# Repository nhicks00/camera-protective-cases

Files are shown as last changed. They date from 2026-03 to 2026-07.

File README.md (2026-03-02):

# Camera Protective Cases (Mevo Start + BirdDog MAKI Live)

Parametric, 3D-printable protective case design workspace for two cameras:
- Mevo Start
- BirdDog MAKI Live

All geometry generation is built with `build123d` (OpenCascade B-REP) and exported as STEP for clean, smooth CAD surfaces.

## Goals
- Tight-fitting protective sleeves for outdoor sports production
- Impact resistance (volleyball strike scenarios)
- Heat/sun durable outer shell (ASA-focused)
- Optional TPU inner shock/fit components
- Precise cutout alignment with device features and ports

## Repository Structure
- `scripts/`: parametric generators for sleeves, liners, and caps
- `models/mevo_case/`: generated Mevo STEP outputs
- `models/mevo_case/reports/`: generated Mevo JSON reports
- `models/maki_case/`: generated MAKI STEP outputs
- `models/maki_case/reports/`: generated MAKI JSON reports
- `refs/`: source reference CAD/STL/PDF assets used for extraction and alignment
- `README_MEVO_CASE.md`: Mevo-specific generator details
- `README_MAKI_CASE.md`: MAKI-specific generator details
- `CHANGELOG.md`: project changelog and current status

## Core Scripts
- `scripts/generate_mevo_case.py`
- `scripts/generate_mevo_start_caps.py`
- `scripts/generate_mevo_start_tpu_liner.py`
- `scripts/generate_mevo_dual_material_case.py`
- `scripts/generate_maki_live_case.py`
- `scripts/generate_maki_live_tpu_liner.py`
- `scripts/generate_maki_live_dual_material_body.py`
- `scripts/generate_maki_live_caps.py`

## Current Outputs
Key generated outputs are in `models/`, including:
- Mevo dual-material body (`TPU_Sleeve` + `ASA_Shell`) + dual-material back cap (`ASA_Back_Cap` + `TPU_Back_Gasket`)
- MAKI ASA sleeve + front/rear caps + TPU sleeve + combined dual-material body (`TPU_Sleeve` + `ASA_Shell`)
- JSON reports for extracted/applied features and dimensions

## Regeneration
```bash
source .venv311/bin/activate

python scripts/generate_mevo_case.py
python scripts/generate_mevo_start_caps.py --profile asa
python scripts/generate_mevo_start_tpu_liner.py
python scripts/generate_mevo_dual_material_case.py

python scripts/generate_maki_live_case.py
python scripts/generate_maki_live_tpu_liner.py
python scripts/generate_maki_live_dual_material_body.py
python scripts/generate_maki_live_caps.py --profile asa
python scripts/generate_maki_live_caps.py --profile tpu
```

Legacy optional command (not part of current Mevo TPU path):
```bash
python scripts/generate_mevo_start_caps.py --profile tpu
```

## Notes
- STEP-only workflow is used for production models.
- Temporary meshes/renders are excluded from version control.
- Output rollover policy:
  - each generator archives existing outputs into `models/mevo_case/archive/` or `models/maki_case/archive/` before writing new files,
  - top-level case folders keep only latest STEP outputs while JSON reports live under each case's `reports/` subfolder.
- See `CHANGELOG.md` for latest engineering status and open alignment tasks.

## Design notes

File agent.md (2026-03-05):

# Agent Context: Camera Protective Cases (Mevo Start + BirdDog MAKI Live)

This file is the persistent handoff context for future sessions.

## Scope
This repo builds parametric, 3D-printable protective case components for:
- Mevo Start
- BirdDog MAKI Live

Primary goals:
- Tight fit
- Outdoor durability
- Impact resistance
- Clean, smooth CAD geometry (not faceted mesh-style approximations)

## Core Modeling Rules
- Use `build123d` (OpenCascade B-REP).
- Export STEP files for deliverables.
- Keep curves smooth; avoid tiny rectangular facet chains for curved surfaces.
- Keep generated outputs organized by camera and archive prior versions.

## Confirmed Dimension Baseline
Use these as the current default stack unless user explicitly overrides.

Mevo Start:
- Device envelope reference: `87.0 x 75.5 x 34.0 mm` (L x H x W)
- TPU inner cavity (active fit): `34.3 x 75.8 x 87.3 mm` (W x H x depth)
- TPU wall: `1.8 mm`
- TPU inner vertical corner fillet: `4.0 mm`
- TPU-to-ASA interface gap: `0.0 mm` (coincident interface)
- ASA shell wall: `2.2 mm`
- ASA outer vertical corner fillet: `6.0 mm`
- Front bucket/sun hood depth: `3.0 mm`
- Front lens cutout: `32.0 mm`
- Front tally LED hole: `3.0 mm`, centered `12.0 mm` above lens center
- Bottom tripod hole: `20.5 mm` diameter, center `43.2 mm` from front face
- ASA back-cap plug lip: `5.0 mm` depth, `0.1 mm` total undersize
- Back utility slot: `15.0 mm` wide, top margin `15.0 mm`, bottom margin `10.0 mm`

BirdDog MAKI Live:
- Device envelope: `120.32 x 56.99 x 56.99 mm` (L x W x H)
- ASA shell wall: `3.0 mm`
- ASA radial clearance to device: `2.3 mm`
- TPU sleeve wall: `2.0 mm`
- TPU radial device clearance: `0.15 mm`
- TPU-to-ASA radial air gap: `0.15 mm` per side (current dual-body default stack)
- ASA cap plug depth: `1.8 mm`

Slicer baseline (ASA):
- 4 wall loops/perimeters minimum.

## Output Organization Policy
- Current outputs:
  - `models/mevo_case/`
  - `models/mevo_case/reports/`
  - `models/maki_case/`
  - `models/maki_case/reports/`
- Each generator archives old versions into:
  - `models/mevo_case/archive/`
  - `models/maki_case/archive/`
- Top-level in each case folder should show only latest STEP outputs for that case.
- JSON reports should live in each case's `reports/` subfolder.

## Current Project State

### MAKI Live (BirdDog)
Active hard-shell and TPU workflows:
- ASA sleeve:
  - `models/maki_case/maki_live_case_sleeve.step`
  - Generator: `scripts/generate_maki_live_case.py`
  - Front is integrated into sleeve by default (`front_integrated=True`).
  - Front cutouts are extracted from STEP and cut through the integrated front wall.
  - Back remains open for separate rear cap installation.
  - Tripod detection is STEP-interrogation-first:
    - cylindrical face detection (thread-radius target near 1/4"-20 geometry),
    - downward axis normal filter,
    - centerline/depth region filters,
    - circular-edge fallback only if cylindrical detection fails.
  - Vent behavior updated to enforced tripod-side 3-panel layout:
    - 8 vent slots on center panel
    - 8 on each adjacent panel
    - 24 total on that side
    - plus side vents: 3 on left side + 3 on right side
    - total applied vents on sleeve: 30
  - The 24-vent bank is constrained to bottom-connected panels (not direct side walls).
  - Side 3+3 vent group is placed on the opposite end from the tripod-side vent bank.
  - Side 3+3 vent dimensions are matched to the main tripanel vent style size.
  - Main `24` vent bank and side `3+3` vents use rounded-slot cuts on both ASA and TPU (not box/square cuts).
  - Vent-bank/tripod side relationship is explicit: 24-bank and tripod opening remain on the same expected side (`tripod_expected_side`), with hood on the opposite side.
  - Front camera aperture in integrated front wall is trimmed by `2.0 mm` vs prior extraction.
  - Through-cut depth increased so vents fully penetrate.
  - Vent row clustering now locks to the STEP-derived rear vent bank (8 rows) and ignores front outlier slots.
  - Tripod armor boss has been removed (params zeroed out).
  - Tripod hole cut orientation is corrected and validated as a true through-cut.
  - Dual-body tripod overlap is now numerically aligned (`dx=0.0`, `dz=0.0` in current reports).
  - Side `3 + 3` vents are rounded-slot cuts (not hard rectangular box cuts).
  - Integrated top-front lens hood/shade uses an extended curved duck-bill profile with curved root transition (`lens_hood_*` params in case script).
  - Vent pass-through validated (`30/30` total) and vent coordinates emitted in report under `step_side_features.vents_applied_entries`.
- ASA caps:
  - Active outputs:
    - `models/maki_case/maki_live_rear_cap_dual_material.step`
  - Generator: `scripts/generate_maki_live_rear_cap_dual_material.py`
  - Dual rear cap contains: `ASA_Back_Cap` + `TPU_Back_Gasket`.
  - TPU rear-cap body now includes:
    - full-face pad at plug-tip contact plane,
    - perimeter edge-wrap collar for back-edge/corner shock isolation,
    so the camera back contacts TPU instead of bare ASA.
  - Legacy rear-cap-only generator remains available (`scripts/generate_maki_live_caps.py --profile asa`).
  - Rear cutouts are extracted from all STEP solids with tiny-hole filtering to preserve port access cutouts over corner fastener holes.
  - Rear cap port cutouts include default oversize clearance (`cutout_extra_mm=1.5`) for cable boot/plastic strain-relief fit.
- TPU one-piece sleeve (preferred TPU output):
  - `models/maki_case/maki_live_tpu_sleeve.step`
  - Generator: `scripts/generate_maki_live_tpu_liner.py`
  - Single connected TPU sleeve with front edge wrap disabled (ASA front wall provides retention) and rear edge wrap disabled by default.
  - Rear remains open for insertion; rear-side TPU contact is handled by rear cap TPU gasket.
  - Side `3 + 3` vents are rounded-slot cuts to match ASA style.
  - Does not use full TPU face caps.
  - Vent pass-through validated (`30/30` through by ray-check), with tripod through-cut also validated.
  - Vent rows are aligned to the ASA sleeve vent coordinates in device frame.
  - Applied empirical vent alignment deltas from tripod-registered overlay:
    - tripanel bank Z shift: `-4.226 mm`
    - side-trio bank Z shift: `-13.397 mm`
  - 24-grid lateral spacing calibration:
    - center column remains fixed
    - left/right columns are inset toward center by `2.6 mm` each
    - resulting tripanel X centers: `-13.4, 0.0, +13.4 mm`
  - Legacy separate TPU liner/caps and unibody files are archived automatically.
- Dual-material body assembly (combined slicer object):
  - `models/maki_case/maki_live_body_dual_material.step`
  - Generator: `scripts/generate_maki_live_dual_material_body.py`
  - Contains two bodies: `TPU_Sleeve` + `ASA_Shell`.
  - TPU is auto-aligned into ASA cavity with report-verified fit stack (default `0.15 mm` radial gap each side, ~`2.1 mm` axial front/back gap).
  - Fit validation pipeline:
    - Script: `scripts/validate_maki_live_fit.py`
    - Output assembly: `models/maki_case/maki_live_fit_validation_assembly.step`
    - Output report: `models/maki_case/reports/maki_live_fit_validation_report.json`
    - Validates real device STEP placement inside body + rear cap and reports pairwise hard-collision volumes.
    - Also validates all major opening geometry against STEP-derived expectations:
      - 24 tripanel vents + 6 side vents for both ASA and TPU bodies,
      - tripod opening alignment for both ASA and TPU,
      - rear-cap cutout center/size matching against STEP-derived rear port cutouts.
    - Current baseline result: no hard collisions and all feature checks passing.

### Mevo Start
Current preferred workflow:
- Dual-material bucket-body workflow (primary):
  - `models/mevo_case/mevo_start_body_dual_material.step`
  - `models/mevo_case/mevo_start_back_cap_dual_material.step`
  - Generator: `scripts/generate_mevo_dual_material_case.py`
  - Body STEP contains named solids: `TPU_Sleeve`, `ASA_Shell`.
  - Back-cap dual STEP contains named solids: `ASA_Back_Cap`, `TPU_Back_Insert`.
- Geometry intent:
  - ovular/capsule-profile sleeve geometry (not rounded-rectangle profile),
  - front-integrated body by default (front wall fused to sleeve),
  - TPU body uses front edge wrap only (rear wrap disabled) to keep insertion path open,
  - front lens/LED cutouts enabled by default in closed-front mode,
  - lens opening defaults updated to `29.5 mm` at `Y=20.0` for improved framing,
  - integrated curved duck-bill front visor is enabled by default (`depth=16 mm`, `drop=9 mm`, `span_ratio=0.90`),
  - thermal venting defaults: top holes enabled plus side slot vents enabled; top-hole plane orientation is corrected to the hood/top side,
  - separate back-cap assembly with TPU gasket (ASA-only cap exported for compatibility),
  - manual two-cutout rear-cap layout is default-enabled (`include_manual_back_cutouts=true`):
    - lower slot from Mevo edge offsets (10 mm side margins, 7 mm bottom offset),
    - upper domed cutout using top offsets (3.0 mm and 28.0 mm from top, 3.0 mm side margins),
  - TPU-aware back-cap fit clearance default: `0.28 mm` total undersize,
  - two-stage tongue engagement with matching rear body groove seat,
  - bottom tripod opening is enlarged to `25.4 mm` with local bottom flattening + TPU relief to keep the opening clear.
  - rear TPU insertion relief is enabled (`5.4 mm` default) so the back-cap plug can seat without colliding with sleeve TPU.
- Mevo back cap utility slot is default-disabled (`include_back_utility_slot=false`) until exact rear port map is confirmed.
- Mevo lens opening uses offset center (`lens_center_y_mm=20.0`) to avoid centered misalignment.
- Optional flags:
  - `--open-front-ovular` for legacy open-front mode,
  - `--disable-front-lens-led-cutouts` to keep front wall solid.
- Active review-spec values are recorded in `models/mevo_case/reports/mevo_start_dual_material_report.json`.
- Legacy open-through/cap workflows remain in repo for fallback only and are not the active default path.
- Note: manufacturer STEP-based auto-extraction is currently strongest for MAKI.
  Mevo workflow is dimension/spec-driven unless a full Mevo STEP is provided.

## Terminology Mapping (Important for user shorthand)
User shorthand often means:
- “Maki sleeve” = ASA outer sleeve (`maki_live_case_sleeve.step`)
- “TPU sleeve for Maki” = `maki_live_tpu_sleeve.step` (single part)
- “Maki caps” = dual-material rear cap by default (`maki_live_rear_cap_dual_material.step`)
- “Mevo rear closure” = `mevo_start_back_cap_dual_material.step` (ASA cap + TPU gasket)
- “Mevo case back plate” = legacy/optional only

## Key References
- MAKI references:
  - `refs/BirdDog_MAKI-Live_3D-file.step`
  - `refs/MAKI-Live_drawing.pdf`
- Mevo references:
  - `refs/Mevo_Start_lens_cover_corrected.stl`
  - Additional Mevo legacy refs are present in `refs/`.

## Common Commands
Activate environment:
```bash
source .venv311/bin/activate
```

MAKI:
```bash
python scripts/generate_maki_live_case.py
python scripts/generate_maki_live_tpu_liner.py
python scripts/generate_maki_live_dual_material_body.py
python scripts/generate_maki_live_rear_cap_dual_material.py
python scripts/validate_maki_live_fit.py
```

Mevo:
```bash
python scripts/generate_mevo_dual_material_case.py
```

Legacy Mevo back plate (only when explicitly requested):
```bash
python scripts/generate_mevo_case.py --include-back-plate
```

## Session Continuity Guidance
When the user gives brief or “random” update requests, assume they refer to this context and default behaviors unless they explicitly override:
- Keep MAKI TPU as one connected sleeve (`maki_live_tpu_sleeve.step`).
- Keep Mevo with single rear closure (rear cap path).
- Maintain archive hygiene policy.
- Preserve smooth B-REP output quality.

If the user asks for changes that affect fit/alignment:
- Regenerate relevant model(s).
- Check the JSON report in the case `reports/` subfolder.
- Verify outputs are single-solid STEP where applicable.
- Keep latest STEP outputs at top level and auto-archive previous versions.

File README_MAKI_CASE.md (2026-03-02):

# BirdDog MAKI Live Protective Case (Parametric Sleeve)

This project now includes a printable protective sleeve generated from the MAKI Live STEP model and validated against the provided drawing dimensions.

## Inputs Used
- `refs/BirdDog_MAKI-Live_3D-file.step`
- Drawing: `MAKI-Live_drawing.pdf` (nominal dimensions used)

## Nominal Constraints Applied
- Width: `56.99 mm`
- Height: `56.99 mm`
- Length: `120.32 mm`

## Generated Outputs
- `models/maki_case/maki_live_case_sleeve.step`
- `models/maki_case/reports/maki_live_case_report.json`
- `models/maki_case/maki_live_tpu_sleeve.step`
- `models/maki_case/reports/maki_live_tpu_sleeve_report.json`
- `models/maki_case/maki_live_body_dual_material.step` (single STEP with `TPU_Sleeve` + `ASA_Shell`)
- `models/maki_case/reports/maki_live_dual_material_report.json`

Archive policy:
- Previous versions are auto-moved to `models/maki_case/archive/` before new files are written.

## Design Characteristics
- Tight, one-piece sleeve
- Front-integrated shell by default (front wall fused to sleeve, rear remains open)
- Default ASA internal clearance: `2.3 mm`
- Default ASA wall thickness: `3.0 mm`
- TPU sleeve defaults:
  - internal camera clearance: `0.2 mm`
  - TPU wall thickness: `2.0 mm`
  - TPU-to-ASA radial gap: `0.1 mm`
  - edge-wrap depth: `2.5 mm`
  - edge-wrap radial hold: `2.0 mm`
- Tripod-side access opening around detected `1/4"-20` region
- Tripod region reinforcement via local external armor boss
- Side vent slots extracted from STEP across flat + corner side panels
- Tripod location extraction is B-Rep based (cylindrical-face-first, circular-edge fallback)
- Enforced vent layout on tripod side: `3` adjacent panels x `8` slots each (`24` total), with through-cuts
- Vent coordinates are reported (`step_side_features.vents_applied_entries`) for ASA/TPU alignment audits.
- Built with `build123d` (OpenCascade B-Rep), exported as STEP only

## Generator Script
- `scripts/generate_maki_live_case.py`

## TPU Sleeve (Single Print)
- `scripts/generate_maki_live_tpu_liner.py`
- Output: `models/maki_case/maki_live_tpu_sleeve.step`
- Output report: `models/maki_case/reports/maki_live_tpu_sleeve_report.json`
- Purpose: one connected TPU sleeve with thin front/rear edge wraps (not full face caps).

Generate one-piece TPU sleeve:
```bash
source .venv311/bin/activate
python scripts/generate_maki_live_tpu_liner.py
```

Useful TPU sleeve tuning:
```bash
python scripts/generate_maki_live_tpu_liner.py \
  --clearance 0.2 \
  --thickness 2.0 \
  --edge-wrap-depth 2.5 \
  --edge-wrap-radial 2.0 \
  --end-clearance 0.2
```

Legacy note:
- `scripts/generate_maki_live_tpu_unibody.py` still exists for older full fused-cap style, but current preferred TPU workflow is `maki_live_tpu_sleeve.step`.

## Dual-Material Body Assembly (Single Combined STEP)
- `scripts/generate_maki_live_dual_material_body.py`
- Output: `models/maki_case/maki_live_body_dual_material.step`
- Output report: `models/maki_case/reports/maki_live_dual_material_report.json`
- Purpose: export one combined slicer-ready assembly containing:
  - `ASA_Shell` body
  - `TPU_Sleeve` insert

Generate combined dual-material body:
```bash
source .venv311/bin/activate
python scripts/generate_maki_live_dual_material_body.py
```

## Front/Rear Caps
- `scripts/generate_maki_live_caps.py`
- Default outputs:
  - `models/maki_case/maki_live_rear_cap.step`
  - `models/maki_case/reports/maki_live_caps_report.json`
- Optional legacy output:
  - `models/maki_case/maki_live_front_cap.step` (only when `--include-front-cap` is used)
- Cap cutouts are extracted from front/rear end-face loop geometry in the original STEP model.
- End-plane anchoring is reported in `report.cutouts.end_planes` to verify extraction reference planes.
- Front cap geometry uses an inverted bezel profile:
  - raised outer rim,
  - recessed center panel,
  - rear-side plug (instead of front-side center protrusion).
- ASA cap plug depth default is `1.8 mm` (tuned to clear the TPU sleeve end-stack).

Generate ASA caps:
```bash
python scripts/generate_maki_live_caps.py --profile asa
```

Generate ASA caps including legacy front cap:
```bash
python scripts/generate_maki_live_caps.py --profile asa --include-front-cap
```

Generate TPU caps (legacy separate parts):
```bash
python scripts/generate_maki_live_caps.py --profile tpu
```

TPU cap outputs:
- `models/maki_case/maki_live_tpu_front_cap.step`
- `models/maki_case/maki_live_tpu_rear_cap.step`
- `models/maki_case/reports/maki_live_tpu_caps_report.json`

Regenerate:
```bash
source .venv311/bin/activate
python scripts/generate_maki_live_case.py
```

Useful tuning flags:
```bash
python scripts/generate_maki_live_case.py \
  --clearance 2.3 \
  --wall 3.0 \
  --lens-d 30 \
  --tripod-z 48
```

## Print Notes (ASA/PETG)
- 0.2 mm layers
- 4 perimeters (wall loops) minimum
- 25-40% gyroid infill
- Print with rear opening up to keep supports low
- If fit is still too tight, increase `--clearance` to `2.9` or `3.1`

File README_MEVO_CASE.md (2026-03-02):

# Mevo Start Protective Case (Parametric)

This workspace now includes a parametric two-piece, print-ready enclosure derived from your reference front-cap STL.

Current focus option:
- front-integrated dual-material body + separate dual-material back cap (`mevo_start_back_cap_dual_material.step`)

## Generated Outputs
- `models/mevo_case/mevo_start_case_body.step`
- `models/mevo_case/reports/mevo_start_case_report.json`
- `models/mevo_case/mevo_start_tpu_sleeve.step`
- `models/mevo_case/reports/mevo_start_tpu_sleeve_report.json`
- `models/mevo_case/mevo_start_body_dual_material.step` (single STEP with `TPU_Sleeve` + `ASA_Shell`)
- `models/mevo_case/mevo_start_back_cap_dual_material.step` (single STEP with `ASA_Back_Cap` + `TPU_Back_Gasket`)
- `models/mevo_case/mevo_start_back_cap_asa.step` (compatibility ASA-only export)
- `models/mevo_case/reports/mevo_start_dual_material_report.json`

Archive policy:
- Previous versions are auto-moved to `models/mevo_case/archive/` before new files are written.

## Design Summary
- Tight-fitting architecture with body + cap options
- Front profile extracted from `refs/Mevo_Start_lens_cover_corrected.stl` (default)
- Dimension-locked to Mevo Start nominal envelope by default:
  - `87.0 mm` length (front-to-back)
  - `75.5 mm` front-profile major axis
  - `34.0 mm` front-profile minor axis
- Internal ASA clearance default: `2.3 mm`
- Main ASA wall default: `3.0 mm`
- Front-integrated dual-material body default (closed front wall with lens/LED cutouts)
- TPU sleeve defaults:
  - internal camera clearance: `0.2 mm`
  - TPU wall thickness: `2.0 mm`
  - TPU-to-ASA radial gap: `0.1 mm`
- Required access implemented:
  - Front lens + LED openings in integrated front wall
  - Rear utility slot on separate back cap
  - Bottom tripod access opening
- Optional side vent slots included
- Tripod impact zone includes an external armor pad on the sleeve body.
- Bottom tripod access uses a centered circular through-hole (`12.7 mm` default).
- Vent openings are kept sharp/right-angled by default (no Y-axis fillet pass on body).

For alternate cap STLs where the inner circular opening is not reliable, the generator still uses the cap for outer curvature and defaults to a manual lens cutout target.
The current default profile logic uses the cap's **inner pill loop** and enforces a symmetric capsule profile before extending to full length.
The solid modeling is done with `build123d` (OpenCascade B-Rep) and exported as STEP only.

## Regenerate
```bash
source .venv311/bin/activate
python scripts/generate_mevo_case.py
```

Export legacy case back plate only when explicitly needed:
```bash
python scripts/generate_mevo_case.py --include-back-plate
```

Generate legacy closed-front sleeve mode (not default):
```bash
python scripts/generate_mevo_case.py --closed-front
```

Generate dual-material body + dual-material back cap (new workflow):
```bash
python scripts/generate_mevo_dual_material_case.py
```

Legacy open-front override:
```bash
python scripts/generate_mevo_dual_material_case.py --open-front-ovular
```

Disable TPU gasket on back cap (fallback):
```bash
python scripts/generate_mevo_dual_material_case.py --disable-back-cap-tpu-gasket
```

Generate Mevo TPU inner sleeve matched to the current ASA shell:
```bash
python scripts/generate_mevo_start_tpu_liner.py
```

Generate legacy Mevo TPU caps (optional, archived workflow):
```bash
python scripts/generate_mevo_start_caps.py --profile tpu
```

Tune TPU sleeve fit stack (example):
```bash
python scripts/generate_mevo_start_tpu_liner.py \
  --device-clearance 0.2 \
  --shell-gap 0.10 \
  --thickness 2.0 \
  --edge-wrap-depth 2.5 \
  --edge-wrap-radial 2.0
```

Enable rear Mevo I/O cutouts on caps (optional):
```bash
python scripts/generate_mevo_start_caps.py --profile asa --rear-io-cutouts
```

Example with explicit dimensions:
```bash
python scripts/generate_mevo_case.py --length-mm 87 --height-mm 75.5 --width-mm 34
```

Use lens opening extracted directly from cap (optional):
```bash
python scripts/generate_mevo_case.py --use-reference-lens-hole
```

The cap generator defaults to:
- Front cap lens opening enabled
- Rear Mevo I/O cutouts disabled (until exact Mevo rear port mapping is confirmed)
- ASA cap plug depth tuned to `1.8 mm` for TPU-compatible assembly stack.

The TPU sleeve generator auto-clamps shell thickness so the sleeve fits inside the ASA shell.
Actual applied thickness and remaining fit margins are written to `models/mevo_case/reports/mevo_start_tpu_sleeve_report.json`.
Current default stack yields:
- radial TPU-to-ASA gap: `0.1 mm` per side
- cap insertion budget with TPU installed: `0.3 mm` remaining per end (with `1.8 mm` ASA cap plug depth)

## Important Fit Note
Port and button positions are parameterized defaults in `scripts/generate_mevo_case.py` and may need small tuning to your exact camera revision and print shrink behavior (ASA + printer profile).

The key tunables are in `CaseParams`:
- `clearance_mm`
- `wall_mm`
- `device_length_mm`, `device_height_mm`, `device_width_mm`
- `power_y_mm`, `audio_y_mm`, `usb_y_mm`
- `tripod_*`

## Suggested Print Setup (ASA)
- 0.4 mm nozzle
- 0.2 mm layer height
- 4 perimeters (wall loops) minimum
- 35–45% gyroid infill (body)
- 100% infill optional around rear plug region
- Anneal/cool slowly to reduce warp

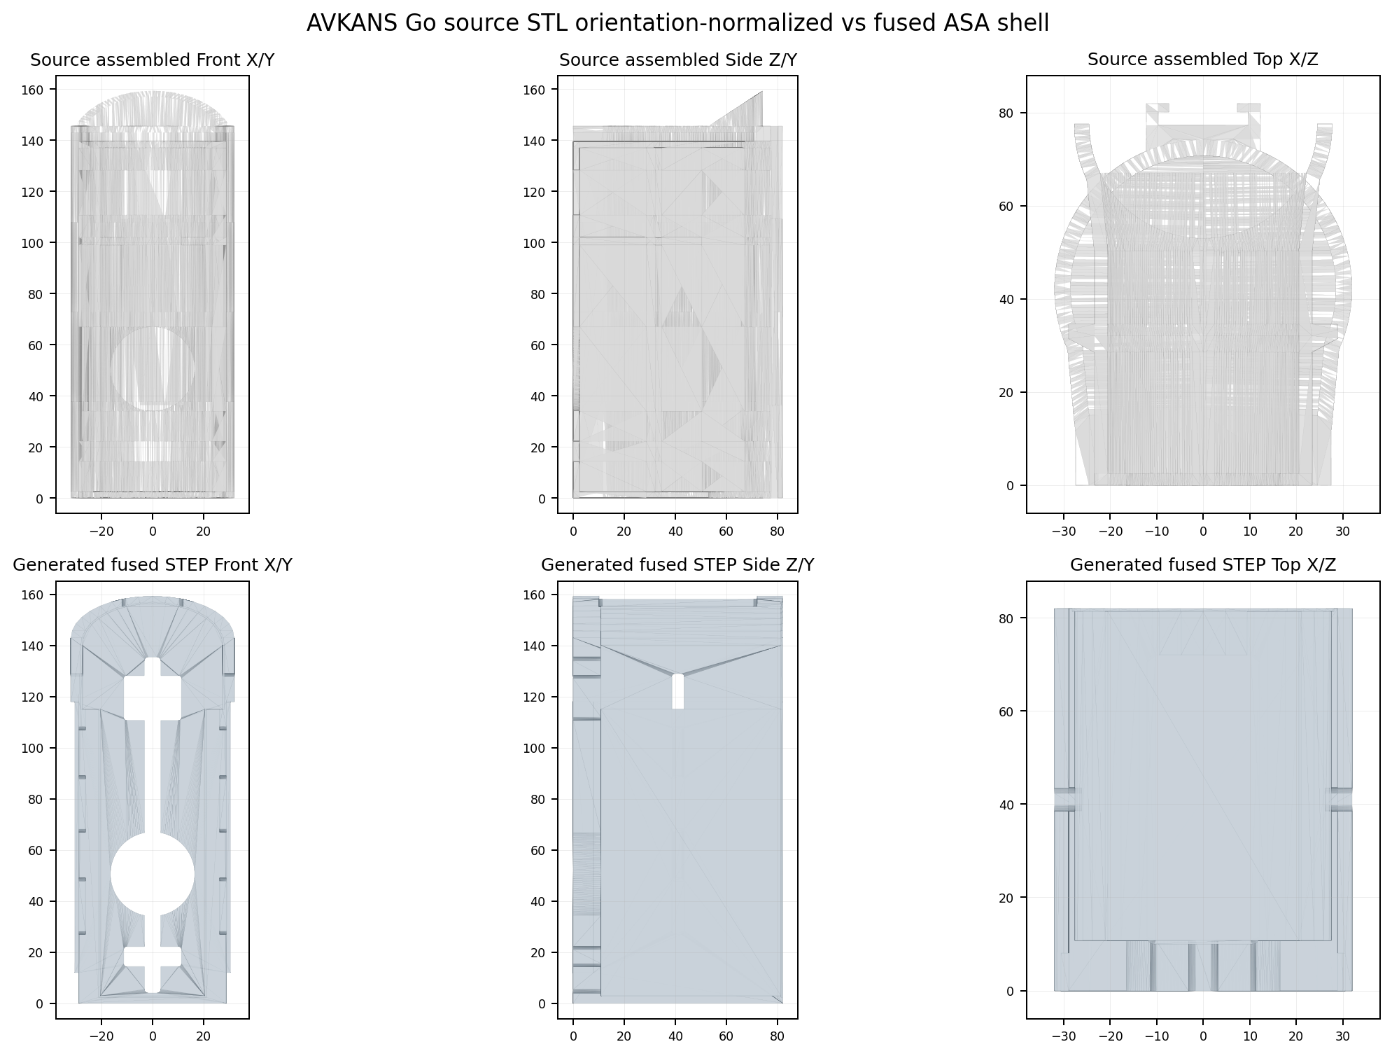
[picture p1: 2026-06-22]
models/avkans_go_case/reports/avkans_go_source_comparison.png

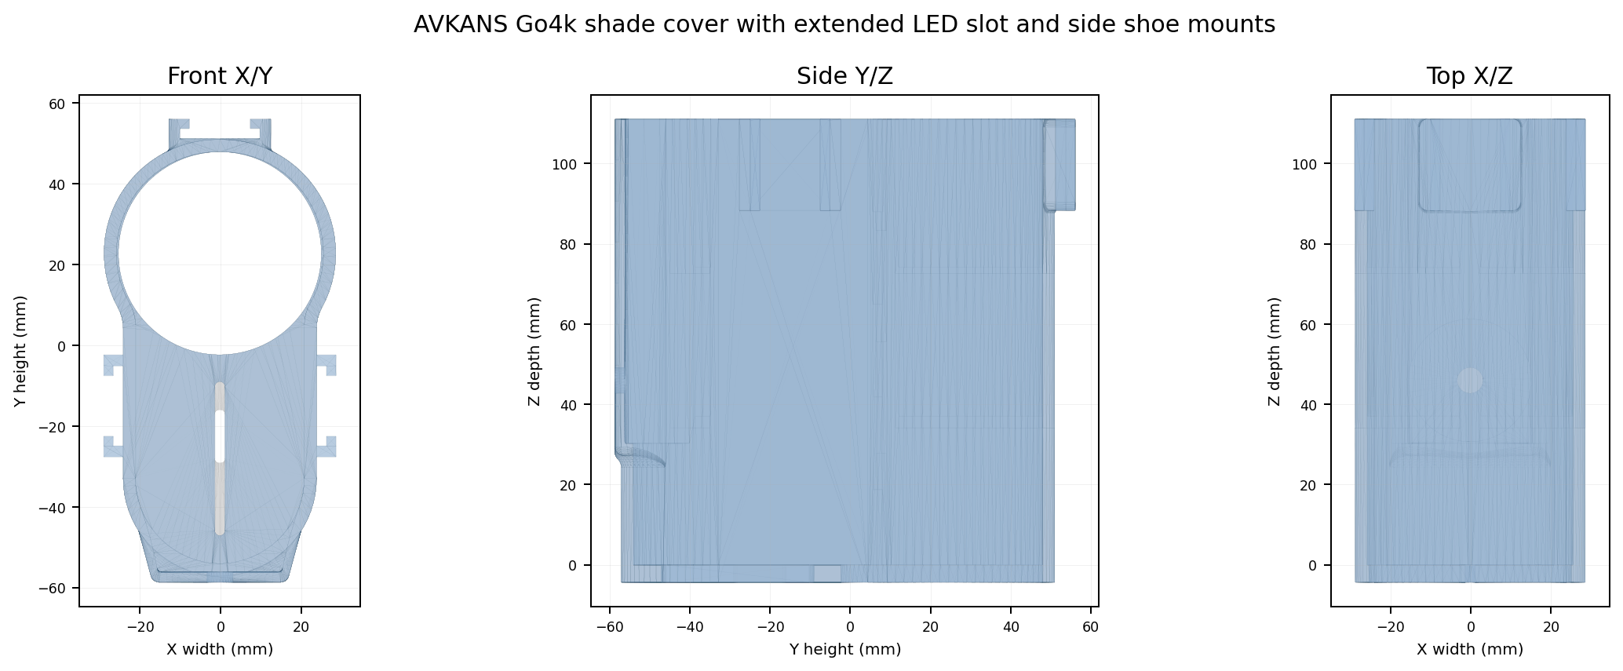
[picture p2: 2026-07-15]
models/avkans_go_case/reports/avkans_go4k_cults_case_preview.png

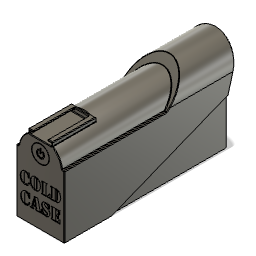
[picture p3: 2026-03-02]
refs/FusionAssetName[Active]/Previews/small.png

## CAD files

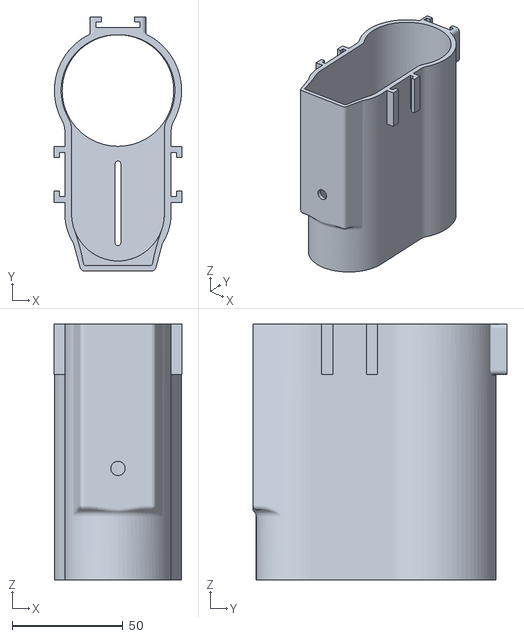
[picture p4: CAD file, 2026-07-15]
models/avkans_go_case/avkans_go4k_cults_shade_extended_led_slot.stl
57.5 x 114.7 x 115.5

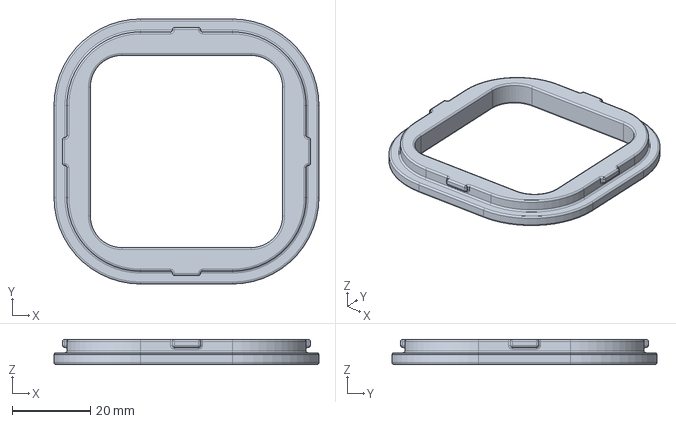
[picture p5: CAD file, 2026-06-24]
models/maki_case/maki_live_back_cap.step
67.6 x 67.6 x 6.40 mm

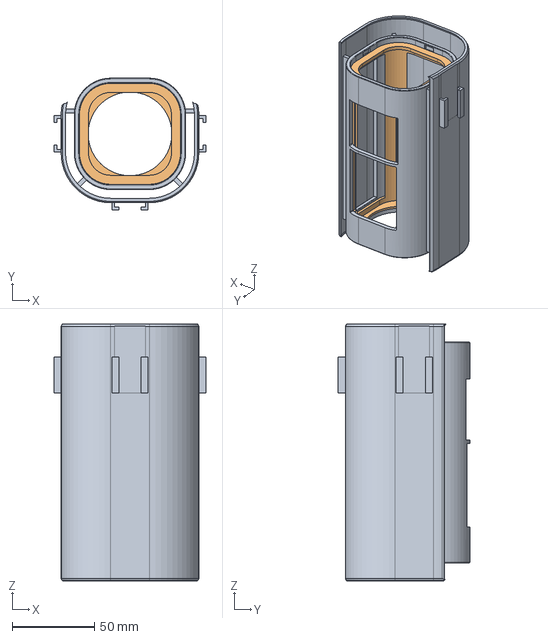
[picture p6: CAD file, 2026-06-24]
models/maki_case/reports/maki_live_body_aligned.step
92.2 x 79.9 x 156.0 mm
ASA_Shell
TPU_Sleeve

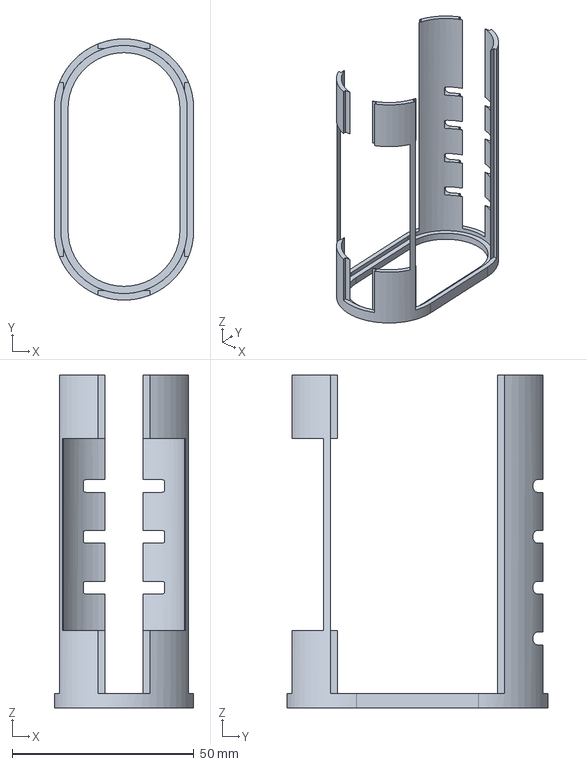
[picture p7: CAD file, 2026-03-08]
models/mevo_case/mevo_start_tpu_frame.step
38.4 x 72.0 x 91.7 mm

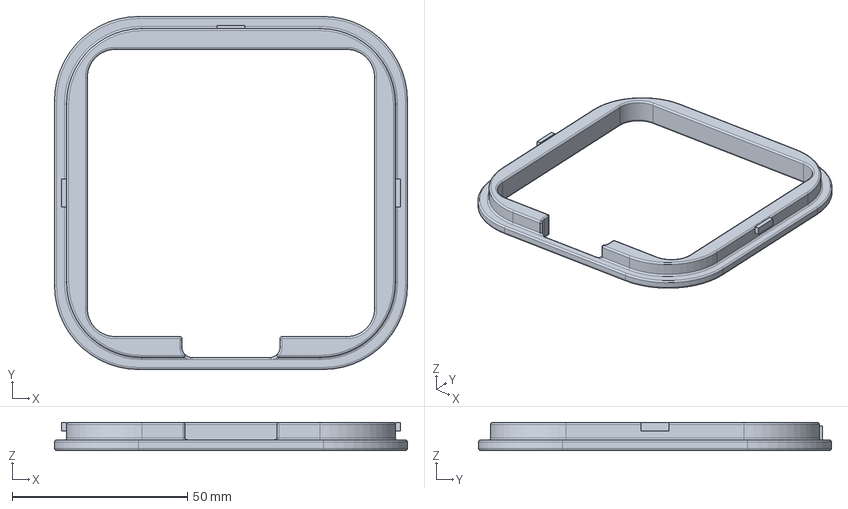
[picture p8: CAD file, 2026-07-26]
models/mevo_core_case/mevo_core_back_cap.step
100.8 x 100.8 x 8.00 mm

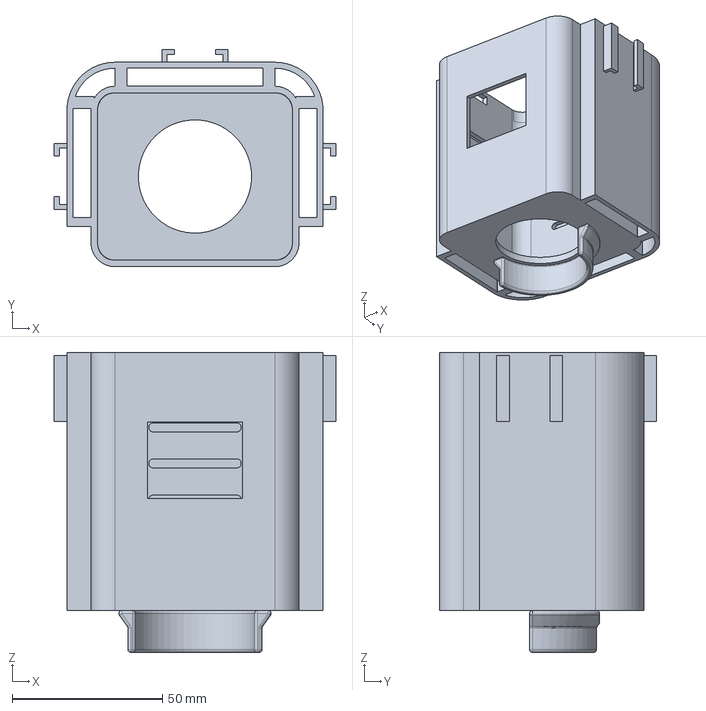
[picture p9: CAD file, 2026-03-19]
models/zowietek_case/zowietek_pov_asa_shell.stp
93.9 x 72.4 x 99.9 mm

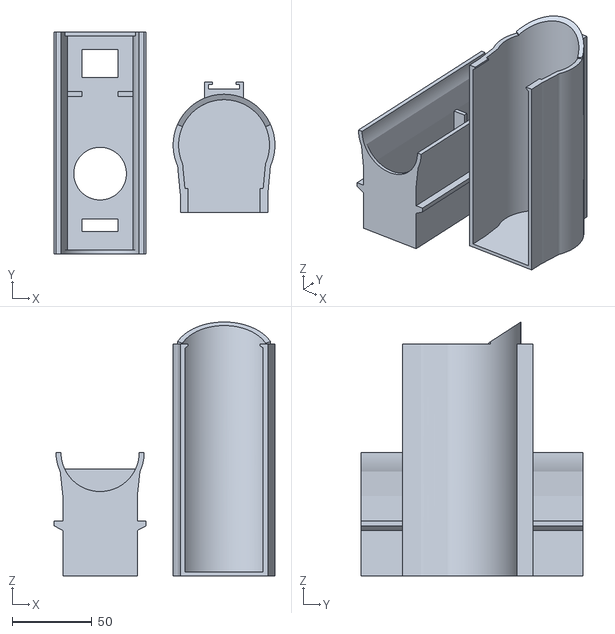
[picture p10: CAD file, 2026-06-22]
refs/AVKANS_GO_RAIN_CASE.stl
138.6 x 139.5 x 159.3

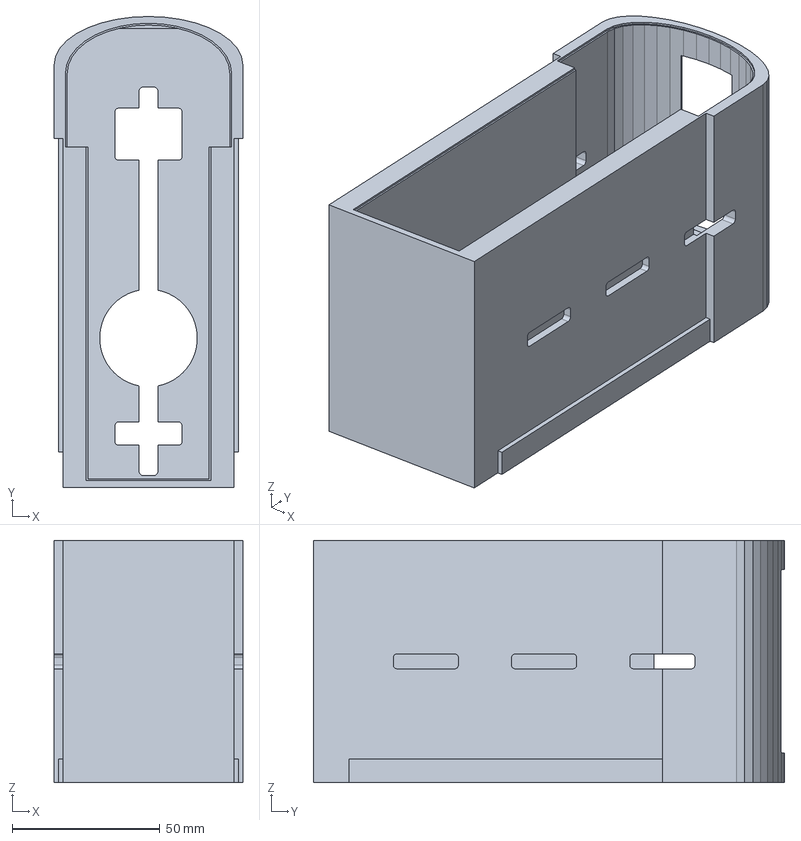
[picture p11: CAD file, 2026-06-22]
models/avkans_go_case/avkans_go_asa_shell.step
63.9 x 159.3 x 81.9 mm

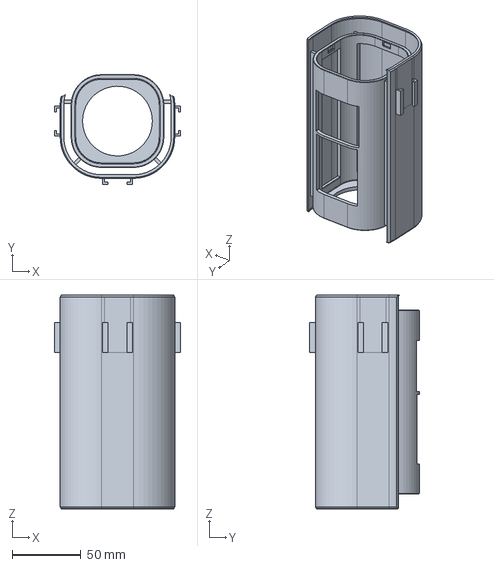
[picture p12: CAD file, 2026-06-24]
models/maki_case/maki_live_case_sleeve.step
92.2 x 79.9 x 156.0 mm

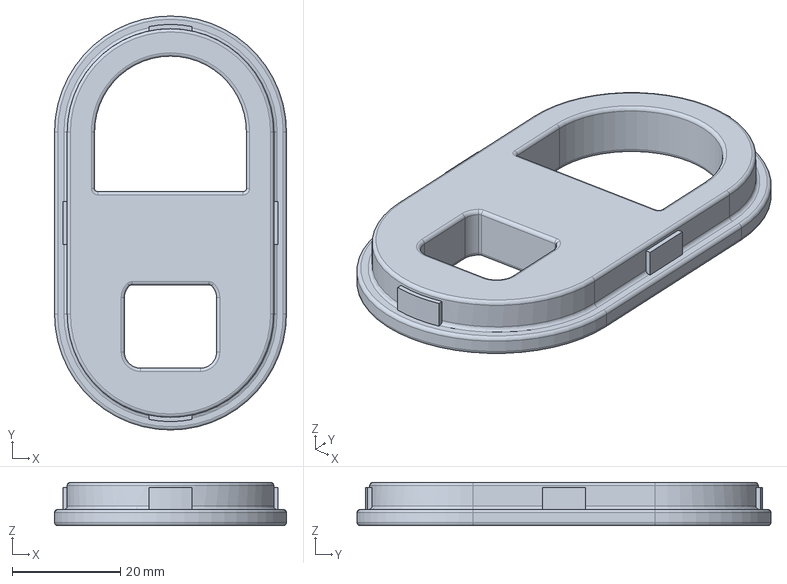
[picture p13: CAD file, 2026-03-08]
models/mevo_case/mevo_start_back_cap.step
42.8 x 76.4 x 8.00 mm

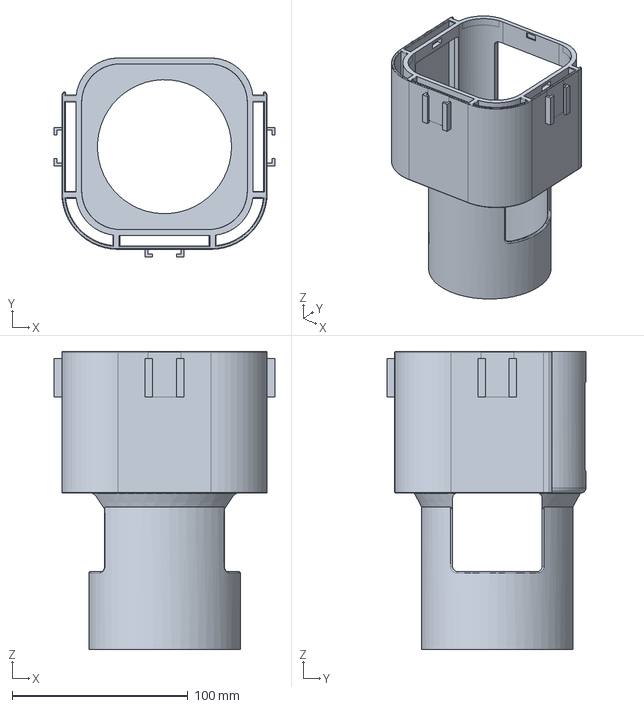
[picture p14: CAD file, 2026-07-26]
models/mevo_core_case/mevo_core_asa_shell.step
125.4 x 113.1 x 169.5 mm

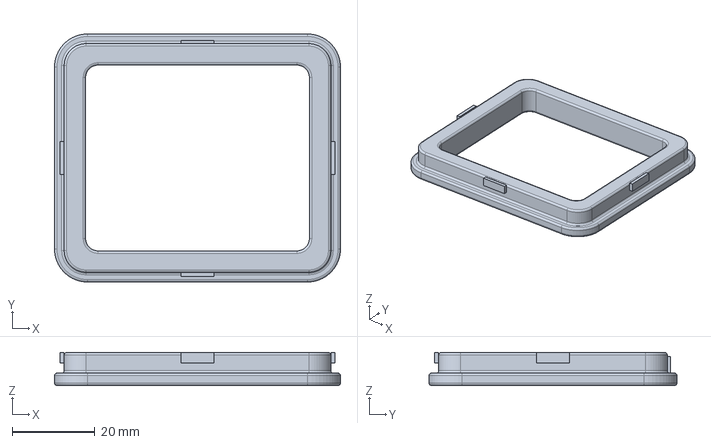
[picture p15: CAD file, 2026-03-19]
models/zowietek_case/zowietek_pov_back_cap.stp
69.3 x 60.1 x 8.00 mm

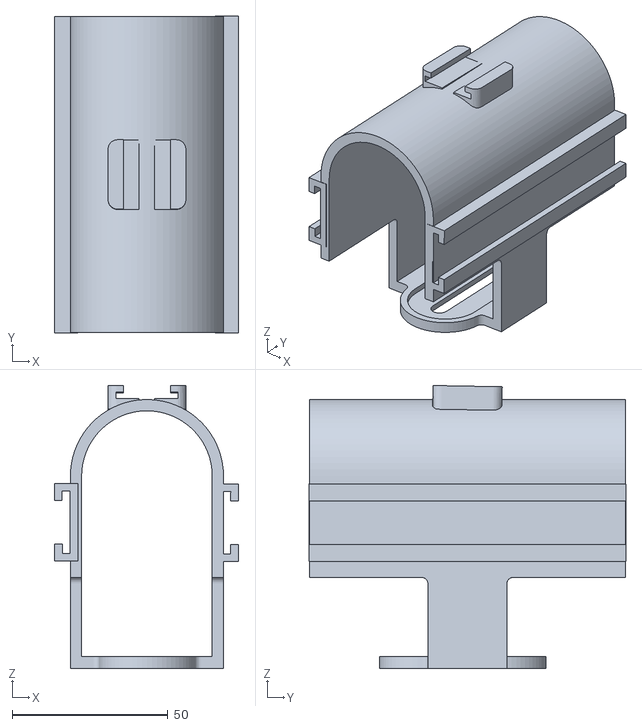
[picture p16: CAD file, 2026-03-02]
refs/mevo_cover_v3_modify_v1.stl
59.2 x 101.9 x 91.0

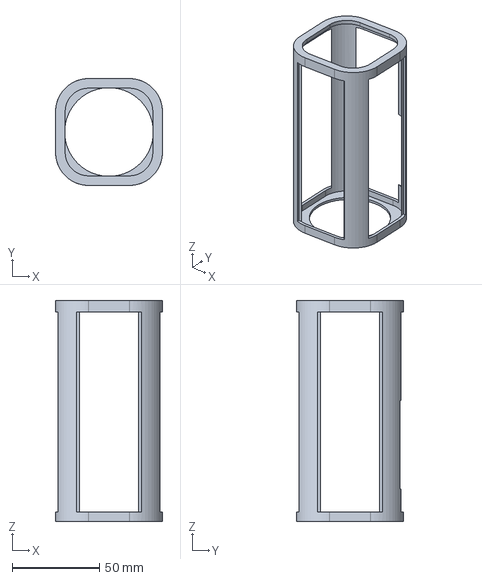
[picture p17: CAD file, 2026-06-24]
models/maki_case/maki_live_tpu_frame.step
61.3 x 61.3 x 126.7 mm

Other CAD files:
models/maki_case/reports/maki_live_rear_cap_aligned.step
models/mevo_case/mevo_start_asa_shell.step
models/zowietek_case/zowietek_pov_tpu_frame.stp
refs/mevo_lens_3.stl
models/avkans_go_case/archive/avkans_go4k_cults_shade_extended_led_slot_20260715_095540.stl
models/avkans_go_case/archive/avkans_go_asa_shell_20260622_160131.step
models/avkans_go_case/archive/avkans_go_asa_shell_20260622_161059.step
models/maki_case/archive/maki_live_asa_shell_20260321_154319.step
models/maki_case/archive/maki_live_asa_shell_20260321_154608.step
models/maki_case/archive/maki_live_asa_shell_20260321_162344.step
models/maki_case/archive/maki_live_asa_shell_20260321_162846.step
models/maki_case/archive/maki_live_asa_shell_20260321_163603.step
models/maki_case/archive/maki_live_asa_shell_20260321_165232.step
models/maki_case/archive/maki_live_asa_shell_20260321_165516.step
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

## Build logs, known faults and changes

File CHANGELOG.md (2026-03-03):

# Changelog

## 2026-03-02

### MAKI Orientation + Hood Curvature Correction
- Corrected MAKI orientation constraints so critical features stay on intended sides:
  - `24`-vent bank and tripod opening are forced to the same configured side (`tripod_expected_side`, default `neg`),
  - front duck-bill hood is forced to the opposite side.
- Added side override behavior for tripod placement:
  - detection side is still recorded (`detected_side`),
  - applied cut side follows expected-side policy for consistent print orientation.
- Updated MAKI duck-bill hood profile to remove straight cross-cut behavior at the camera opening:
  - hood root shape now uses a circular intersection with front profile for a more curved transition.
- Applied in:
  - `scripts/generate_maki_live_case.py`
  - `scripts/generate_maki_live_tpu_liner.py`
- Regenerated:
  - `models/maki_case/maki_live_case_sleeve.step`
  - `models/maki_case/maki_live_tpu_sleeve.step`
  - `models/maki_case/maki_live_body_dual_material.step`
  - updated MAKI reports in `models/maki_case/reports/`.

### Mevo Upper Rear Window + Front Lens Lift + Duck-Bill Hood Update
- Updated Mevo upper manual rear cutout (button/headphone area) to be wider and shifted closer to the top while extending lower:
  - side margins changed to `3.0 mm` (from `6.35 mm`)
  - top offset changed to `3.0 mm` (from `6.0 mm`)
  - bottom offset from top changed to `28.0 mm` (from `25.4 mm`)
  - resulting upper domed cutout width now `28.0 mm`
- Updated Mevo front lens opening vertical placement:
  - `lens_center_y_mm` changed from `18.0` to `20.0`
- Added integrated Mevo front duck-bill visor:
  - enabled by default (`include_front_duckbill_hood=true`)
  - depth `16.0 mm`, drop `9.0 mm`, span ratio `0.90`
  - built as a curved top-band extension of the front profile for stronger attachment.
- Regenerated:
  - `models/mevo_case/mevo_start_body_dual_material.step`
  - `models/mevo_case/mevo_start_back_cap_dual_material.step`
  - `models/mevo_case/mevo_start_back_cap_asa.step`
  - `models/mevo_case/reports/mevo_start_dual_material_report.json`

### MAKI Vent/Tripod/Duck-Bill/Rear-Cap TPU Coverage Update
- Updated MAKI `24`-bank vent cuts in both ASA and TPU generators to true rounded-slot geometry:
  - `scripts/generate_maki_live_case.py`
  - `scripts/generate_maki_live_tpu_liner.py`
- Side trio and main bank now share slot-style vent shape language across both materials.
- Fixed MAKI tripod cutout alignment in dual-material body:
  - TPU generator now uses the same tripod extraction strategy as ASA (cylindrical-face-first with circle-edge fallback).
  - Dual overlap verification now reports tripod alignment at `dx=0.0`, `dz=0.0`.
- Replaced prior MAKI front sun-visor bar with a longer integrated curved duck-bill hood:
  - hood depth increased to `16 mm`,
  - top-band profile follows front opening curvature.
- Reworked MAKI dual rear-cap TPU body from recessed ring to full-contact cushioning:
  - full face TPU pad at plug tip plane,
  - perimeter TPU edge-wrap collar for corner/edge protection,
  - cutouts carried through TPU coverage volume.
- Regenerated:
  - `models/maki_case/maki_live_case_sleeve.step`
  - `models/maki_case/maki_live_tpu_sleeve.step`
  - `models/maki_case/maki_live_body_dual_material.step`
  - `models/maki_case/maki_live_rear_cap_dual_material.step`
  - `models/maki_case/maki_live_rear_cap.step`
  - updated MAKI reports under `models/maki_case/reports/`.

### Mevo Lens Opening + Manual Back-Cap Cutouts Update
- Updated Mevo front lens opening in dual-material generator:
  - diameter reduced from `32.0` to `29.5 mm` (2.5 mm smaller)
  - center raised from `Y=16.5` to `Y=18.0`
  - file: `scripts/generate_mevo_dual_material_case.py`
- Added manual rear-cap cutout layout (enabled by default) using device-edge offsets:
  - lower slot:
    - side margins `10 mm` each
    - bottom offset `7 mm`
    - resulting width `14.0 mm`
  - upper domed cutout (half-moon + extended lower section):
    - side margins `6.35 mm` each (0.25 in)
    - top offset `6.0 mm`
    - bottom offset from top `25.4 mm` (1 in)
    - resulting width `21.3 mm`
- Manual cutouts are now applied to both:
  - ASA rear cap body
  - TPU rear-cap gasket body
- Regenerated outputs:
  - `models/mevo_case/mevo_start_body_dual_material.step`
  - `models/mevo_case/mevo_start_back_cap_dual_material.step`
  - `models/mevo_case/mevo_start_back_cap_asa.step`
  - `models/mevo_case/reports/mevo_start_dual_material_report.json`

### MAKI Side-Vent Geometry + Alignment + Lens-Hood + Rear-Cap Contact Fix
- Updated MAKI side `3 + 3` vents (both ASA + TPU generators) to rounded slot cuts instead of box cuts:
  - `scripts/generate_maki_live_case.py`
  - `scripts/generate_maki_live_tpu_liner.py`
- Corrected ASA side-trio mirrored Z placement in integrated-front mode so side vents align with TPU in dual-material assembly.
  - Verified in report math: side-trio aligned `dz = 0.0` after dual-body placement offset.
- Added integrated top-front lens hood/shade geometry to MAKI ASA sleeve:
  - default enabled in `scripts/generate_maki_live_case.py`
  - report now includes `derived.lens_hood` metadata.
- Reworked MAKI dual rear-cap TPU gasket contact placement:
  - `scripts/generate_maki_live_rear_cap_dual_material.py`
  - gasket now references plug profile and sits at the plug-tip contact plane (instead of recessed plate-plane ring placement).
- Regenerated outputs:
  - `models/maki_case/maki_live_case_sleeve.step`
  - `models/maki_case/maki_live_tpu_sleeve.step`
  - `models/maki_case/maki_live_body_dual_material.step`
  - `models/maki_case/maki_live_rear_cap_dual_material.step`
  - `models/maki_case/maki_live_rear_cap.step`
  - updated corresponding JSON reports under `models/maki_case/reports/`.

### Rear-Insertion Fit Rule Update (MAKI + Mevo)
- Updated TPU body behavior to keep rear insertion open by default:
  - front edge-wrap enabled,
  - rear edge-wrap disabled.
- Applied in:
  - `scripts/generate_maki_live_tpu_liner.py`
  - `scripts/generate_mevo_start_tpu_liner.py`
  - `scripts/generate_maki_live_dual_material_body.py`
  - `scripts/generate_mevo_dual_material_case.py`
- Added explicit CLI toggles for edge-wrap behavior in Mevo/MAKI dual-body workflows.
- Added MAKI dual-material rear cap generator:
  - `scripts/generate_maki_live_rear_cap_dual_material.py`
  - outputs:
    - `models/maki_case/maki_live_rear_cap_dual_material.step` (`ASA_Back_Cap` + `TPU_Back_Gasket`)
    - `models/maki_case/maki_live_rear_cap.step` (ASA-only compatibility export)
    - `models/maki_case/reports/maki_live_rear_cap_dual_material_report.json`
- Regenerated primary current files:
  - `models/maki_case/maki_live_body_dual_material.step`
  - `models/maki_case/maki_live_tpu_sleeve.step`
  - `models/maki_case/maki_live_rear_cap_dual_material.step`
  - `models/mevo_case/mevo_start_body_dual_material.step`
  - `models/mevo_case/mevo_start_back_cap_dual_material.step`
  - `models/mevo_case/mevo_start_tpu_sleeve.step`
- Validation in reports confirms target state:
  - TPU body edge-wrap: `front=true`, `rear=false`
  - rear-cap TPU contact/gasket enabled on both camera families.

### MAKI Combined Dual-Material Body Export
- Added `scripts/generate_maki_live_dual_material_body.py`.
- New output:
  - `models/maki_case/maki_live_body_dual_material.step` (single STEP assembly with `TPU_Sleeve` + `ASA_Shell`)
  - `models/maki_case/reports/maki_live_dual_material_report.json`
- The new generator composes existing validated MAKI ASA + TPU generators and aligns TPU into ASA automatically.
- Report includes:
  - axial alignment offset,
  - front/back axial gaps,
  - radial fit gaps,
  - warnings for any interference.
- Default fit verified in report:
  - radial gap: `~0.1 mm` each side,
  - axial front/back gap: `~2.1 mm` each end.

### MAKI Side-Trio Vent Size Correction
- Increased side `3 + 3` vent cutout dimensions (kept location and count unchanged):
  - previous side trio size was about `4.37 x 1.50 mm` (ASA) and `4.42 x 1.55 mm` (TPU),
  - updated side trio size now about `7.00 x 2.25 mm` (ASA) and `7.08 x 2.33 mm` (TPU).
- The 24-vent bottom-connected bank (`8 x 3`) was intentionally left unchanged.
- Applied in:
  - `scripts/generate_maki_live_case.py`
  - `scripts/generate_maki_live_tpu_liner.py`
- Regenerated and validated through-cuts:
  - ASA vents open: `30/30`
  - TPU vents open: `30/30`

### MAKI Side-Trio Exact-Style Sizing + Front Camera Aperture Trim
- Updated side `3 + 3` vents again to match the full vent style size from the main vent bank:
  - side trio now matches tripanel slot dimensions (ASA and TPU), rather than using reduced scaled values.
- Reduced MAKI front camera aperture opening by `2.0 mm`:
  - applied to integrated-front sleeve extraction (`generate_maki_live_case.py`)
  - applied to front-cap extraction logic (`generate_maki_live_caps.py`) for consistency.
- Regenerated:
  - `models/maki_case/maki_live_case_sleeve.step`
  - `models/maki_case/maki_live_tpu_sleeve.step`
  - `models/maki_case/maki_live_body_dual_material.step`
  - `models/maki_case/maki_live_rear_cap.step`
  - reports updated under `models/maki_case/reports/`

### Mevo Production Assembly Upgrade (Dual-Material Back Cap + TPU-Aware Fit)
- Updated `scripts/generate_mevo_dual_material_case.py` for a production-oriented two-part assembly workflow:
  - Main body remains dual-material (`TPU_Sleeve` + `ASA_Shell`).
  - Back cap is now generated as a dual-material assembly (`ASA_Back_Cap` + `TPU_Back_Gasket`).
  - Compatibility ASA-only cap export is still generated.
- Implemented TPU-aware back-cap fit tuning:
  - Back-cap lip undersize changed from `0.10 mm` to `0.28 mm` total for more reliable real-world insert/removal with TPU interfaces.
- Implemented tongue-and-groove style engagement:
  - Added a two-stage cap lip (wider tongue stage + slimmer friction stage).
  - Added matching rear groove seat in the main body opening.
- Added back-cap TPU gasket ring:
  - Default enabled, thin inner-face gasket for damped closure and reduced rattle.
- New outputs:
  - `models/mevo_case/mevo_start_back_cap_dual_material.step`
  - `models/mevo_case/mevo_start_back_cap_asa.step` (compatibility)
  - updated `models/mevo_case/reports/mevo_start_dual_material_report.json`
  - updated `models/mevo_case/reports/mevo_validation_summary.json`

### MAKI Vent Panel Orientation Correction (Bottom-Connected 24-Bank)
- Corrected MAKI vent panel placement so the `24`-vent bank sits on the tripod-side bottom-connected 3-panel region:
  - center lane `8`
  - adjacent lane left `8`
  - adjacent lane right `8`
- Fixed prior misplacement where the adjacent `16` vents were on the direct side walls.
- Side `3 + 3` vent group was also moved to the opposite end as requested.
- Applied to both:
  - `scripts/generate_maki_live_case.py`
  - `scripts/generate_maki_live_tpu_liner.py`
- Regenerated and validated:
  - `models/maki_case/maki_live_case_sleeve.step`
  - `models/maki_case/maki_live_tpu_sleeve.step`
  - `models/maki_case/reports/maki_live_case_report.json`
  - `models/maki_case/reports/maki_live_tpu_sleeve_report.json`
  - `models/maki_case/reports/maki_validation_summary.json`

### MAKI Vent Pattern Correction (`24 + 6`)
- Corrected MAKI vent layout implementation to match requested pattern:
  - `24` vents above tripod area across the 3-panel bank (`8 x 3`).
  - Plus side vents: `3` on left side and `3` on right side.
- Fixed vent-slot orientation on side/corner panels (previously swapped tangential vs vertical dimensions, which visually collapsed rows into long slits).
- Applied in both generators:
  - `scripts/generate_maki_live_case.py`
  - `scripts/generate_maki_live_tpu_liner.py`
- Regenerated:
  - `models/maki_case/maki_live_case_sleeve.step`
  - `models/maki_case/maki_live_tpu_sleeve.step`
  - `models/maki_case/reports/maki_live_case_report.json`
  - `models/maki_case/reports/maki_live_tpu_sleeve_report.json`
  - `models/maki_case/reports/maki_validation_summary.json`
- Validation result after regeneration:
  - ASA sleeve vents open: `30/30`
  - TPU sleeve vents open: `30/30`
  - Tripod cutout remains open through both ASA and TPU sleeves.

### MAKI Through-Cut Validation + Regeneration (STEP-Driven)
- Fixed MAKI tripod opening generation in both sleeve generators:
  - `scripts/generate_maki_live_case.py`
  - `scripts/generate_maki_live_tpu_liner.py`
- Root cause was side-hole subtraction orientation/placement on XZ/ZX planes; this caused non-through tripod cuts.
- Updated cut generation so tripod openings are true circular through-cuts in both:
  - ASA sleeve (`maki_live_case_sleeve.step`)
  - TPU sleeve (`maki_live_tpu_sleeve.step`)
- Regenerated and verified:
  - MAKI ASA sleeve vents: `24/24` open (8 center `Y` + 16 side `X`)
  - MAKI TPU sleeve vents: `24/24` open
  - MAKI ASA + TPU tripod openings: through-cut and open
  - MAKI rear cap cutouts: `5/5` center-open
- Added validation summary outputs:
  - `models/maki_case/reports/maki_validation_summary.json`
  - `models/mevo_case/reports/mevo_validation_summary.json`

### Cutout Alignment Corrections (MAKI + Mevo)
- MAKI rear-cap extraction fix:
  - `generate_maki_live_caps.py` now interrogates all STEP solids (not just largest solid) when extracting end-face cutouts.
  - Added rear tiny-hole filtering so fastener holes are not mistaken for port access cutouts.
  - Rear-cap report now contains port-sized cutouts (no longer only four corner micro-holes).
- Mevo dual-material cap/front fixes:
  - `generate_mevo_dual_material_case.py` front lens opening moved off-center using `lens_center_y_mm=16.5` to avoid centered-misaligned lens hole behavior.
  - Rear back-cap giant utility slot is now disabled by default (`include_back_utility_slot=false`).
- Regenerated:
  - `models/maki_case/maki_live_case_sleeve.step`
  - `models/maki_case/maki_live_rear_cap.step`
  - `models/maki_case/reports/maki_live_caps_report.json`
  - `models/mevo_case/mevo_start_body_dual_material.step`
  - `models/mevo_case/mevo_start_back_cap_asa.step`
  - `models/mevo_case/reports/mevo_start_dual_material_report.json`

### MAKI Port Oversize + Sleeve Vent/Tripod Alignment Pass
- Updated `generate_maki_live_caps.py`:
  - Increased default port cutout oversize to `1.5 mm` (`cutout_extra_mm=1.5`) to accommodate cable boot width, not just metal connector geometry.
  - Raised rear cutout minimum-size filter to remove corner fastener-hole artifacts from rear-cap port cutouts.
- Updated `generate_maki_live_case.py`:
  - Reworked tripanel vent clustering to lock onto the true 8-row rear vent bank from STEP geometry and avoid front outlier slots.
  - Vent panel centers now derive from STEP side-panel vent families (`x≈left/center/right`) so sleeve vent cuts align with three-panel vent layout.
  - Increased tripod sleeve cutout oversize via dedicated parameter (`tripod_cutout_extra_mm`) for better mounting access.
- Regenerated:
  - `models/maki_case/maki_live_case_sleeve.step`
  - `models/maki_case/maki_live_rear_cap.step`
  - `models/maki_case/reports/maki_live_case_report.json`
  - `models/maki_case/reports/maki_live_caps_report.json`

### Mevo Dual-Material Height/Depth Fit Correction
- Corrected Mevo dual-material default fit envelope to match Mevo Start dimensions:
  - camera nominal: `34.0 x 75.5 x 87.0 mm` (W x H x D)
  - TPU inner cavity (snug): `34.3 x 75.8 x 87.3 mm` (`+0.15 mm` fit clearance per side/end)
- This replaces the undersized prior dual-material defaults (`34.3 x 50.3 x 85.0 mm`) that caused the body to appear too short in height.
- Regenerated:
  - `models/mevo_case/mevo_start_body_dual_material.step`
  - `models/mevo_case/mevo_start_back_cap_asa.step`
  - `models/mevo_case/reports/mevo_start_dual_material_report.json`

### STEP-Interrogation Upgrade For Cutout Accuracy (MAKI)
- Upgraded MAKI feature extraction to follow a direct B-Rep interrogation strategy (build123d `import_step`) instead of relying on implicit guesses.
- `scripts/generate_maki_live_case.py`:
  - Added cylindrical-face-first tripod detection:
    - filters cylindrical faces by thread-radius target (`~3.175 mm` ± tolerance),
    - requires downward thread-axis normal (`-Z`),
    - constrains expected centerline/depth region,
    - falls back to circular-edge detection only if no valid cylinder is found.
  - Report now includes:
    - `step_side_features.tripod_source`
    - `tripod_cyl_candidate_count`
    - `tripod_edge_candidate_count`
    - `tripod_detected_raw` (raw STEP-space center/radius/normal)
    - `tripod_applied` (mapped case-space location used in cutout generation)
- `scripts/generate_maki_live_caps.py`:
  - End-cap cutout extraction now explicitly anchors to detected front/back end planes and then collects internal-loop cutouts on those planes (with tolerance and window fallback).
  - Report now includes `report.cutouts.end_planes` with front/back plane coordinates used for extraction.
- Regenerated MAKI outputs and reports:
  - `models/maki_case/maki_live_case_sleeve.step`
  - `models/maki_case/maki_live_rear_cap.step`
  - `models/maki_case/reports/maki_live_case_report.json`
  - `models/maki_case/reports/maki_live_caps_report.json`

### Front-Integrated Rule Applied (Both Cameras)
- Applied the new assembly rule: front cap is integrated into the sleeve/body; only rear/back cap remains a separate part.
- Mevo dual-material generator (`generate_mevo_dual_material_case.py`):
  - Default changed to closed/front-integrated body (`open_front_ovular=false`).
  - Front lens + LED cutouts are enabled by default in closed-front mode.
  - Added `--open-front-ovular` (legacy override) and `--disable-front-lens-led-cutouts`.
- MAKI sleeve generator (`generate_maki_live_case.py`):
  - Added integrated-front mode as default (`front_integrated=true`).
  - Front-wall cutouts are extracted from source STEP end-face loops and cut through the integrated front wall.
  - Added `--open-front` (legacy override) and `--no-front-cutouts`.
- MAKI cap generator (`generate_maki_live_caps.py`):
  - Default export is now rear-cap only.
  - Front cap export is legacy optional via `--include-front-cap`.
- Regenerated and updated active outputs:
  - `models/mevo_case/mevo_start_body_dual_material.step`
  - `models/mevo_case/mevo_start_back_cap_asa.step`
  - `models/mevo_case/reports/mevo_start_dual_material_report.json`
  - `models/maki_case/maki_live_case_sleeve.step`
  - `models/maki_case/maki_live_rear_cap.step`
  - `models/maki_case/reports/maki_live_case_report.json`
  - `models/maki_case/reports/maki_live_caps_report.json`
- Archived legacy Mevo separate front/rear cap artifacts from top-level outputs.

### Mevo Dual-Body Ovular Profile Regression Fix
- Updated `scripts/generate_mevo_dual_material_case.py` to remove rounded-rectangle default shell generation for the dual body.
- Dual-body defaults now use a true vertical capsule/ovular cross-section for:
  - ASA outer shell profile
  - ASA inner cavity profile
  - TPU outer profile
  - TPU inner cavity profile
- Changed dual-body default front behavior to open ovular front (`open_front_ovular=true`) to match the style of `mevo_start_case_body` and avoid the previous front circular-cutout appearance.
- Added optional CLI controls:
  - `--closed-front`
  - `--enable-front-lens-led-cutouts`
  - `--disable-capsule-profile` (fallback only)
- Regenerated:
  - `models/mevo_case/mevo_start_body_dual_material.step`
  - `models/mevo_case/mevo_start_back_cap_asa.step`
  - `models/mevo_case/reports/mevo_start_dual_material_report.json`

### Mevo Review-Spec Alignment (Dual-Material Bucket + Back Cap)
- Updated `scripts/generate_mevo_dual_material_case.py` to match the latest reviewed Mevo spec exactly:
  - TPU inner cavity: `34.3 x 50.3 x 85.0 mm`
  - TPU wall: `1.8 mm`
  - ASA wall: `2.2 mm`
  - TPU-to-ASA interface gap: `0.0 mm`
  - TPU inner corner radius: `4.0 mm`
  - ASA outer corner radius: `6.0 mm` (now default target, no auto-expansion)
  - Front lens cutout: `32.0 mm`
  - Front LED hole: `3.0 mm` at `+12.0 mm` Y from lens center
  - Sun-hood depth: `3.0 mm`
  - Bottom tripod hole: `20.5 mm` diameter, centered `43.2 mm` from front
  - Back-cap lip: `5.0 mm` depth, `0.1 mm` total undersize
  - Back utility slot: `15.0 mm` width with `15.0 mm` top and `10.0 mm` bottom margins
- Regenerated:
  - `models/mevo_case/mevo_start_body_dual_material.step`
  - `models/mevo_case/mevo_start_back_cap_asa.step`
  - `models/mevo_case/reports/mevo_start_dual_material_report.json`
- Confirmed named solids remain present in the body STEP: `TPU_Sleeve`, `ASA_Shell`.
- Note: this supersedes prior dual-material tripod defaults (`25.4 mm` and earlier `12.7 mm`) for the active Mevo reviewed workflow.

### Mevo Tripod Hole Diameter Update
- Updated Mevo bottom tripod opening default to `25.4 mm` (`1.0 in`) for:
  - `generate_mevo_case.py` (ASA case body)
  - `generate_mevo_start_tpu_liner.py` (TPU sleeve)
  - `generate_mevo_dual_material_case.py` (ASA+TPU dual-material body)
- Regenerated Mevo outputs and reports with the new diameter.

### Mevo Dual-Material Body + Pure ASA Back Cap Workflow
- Added `scripts/generate_mevo_dual_material_case.py`.
- New outputs:
  - `models/mevo_case/mevo_start_body_dual_material.step` (single STEP with named bodies `TPU_Sleeve` and `ASA_Shell`)
  - `models/mevo_case/mevo_start_back_cap_asa.step`
  - `models/mevo_case/reports/mevo_start_dual_material_report.json`
- New default stack in this workflow:
  - TPU internal clearance: `0.15 mm`
  - TPU-to-ASA interface gap: `0.0 mm`
  - Internal vertical fillet target: `3.0 mm` (capsule profile exceeds this requirement)
- Body updated to front-closed bucket architecture with `2.0 mm` lens recess.
- Back cap is separate pure ASA part with built-in USB-C and power button cutouts.

### Vent + Tripod Cutout Corrections
- Mevo sleeve:
  - Replaced bottom tripod opening with a centered circular through-hole (`12.7 mm` default diameter).
  - Disabled Y-axis body filleting by default to keep Mevo vent opening edges sharp/right-angled.
- MAKI sleeve + TPU sleeve:
  - Updated vent subtraction strategy to start cuts outside the shell face and cut inward (eliminates non-through “placeholder” vents).
  - Kept vent rows aligned between ASA and TPU via shared 3-panel/8-row pattern derivation.
  - Added vent-entry reporting (`vents_applied_entries`) for direct coordinate auditing.
- Verified with geometric ray checks:
  - MAKI ASA vents: `24/24` through
  - MAKI TPU vents: `24/24` through
  - MAKI ASA/TPU vent alignment in device frame: max delta `0.0 mm` on x and z for corresponding rows.

### Assembly Fit Hardening + 3.0 mm ASA Wall Update
- Updated default ASA wall thickness to `3.0 mm` for both Mevo and MAKI sleeve/cap workflows.
- Mevo sleeve now defaults to open-through mode for front/rear cap assembly compatibility.
- Reduced ASA cap plug depth defaults to `1.8 mm` (Mevo + MAKI) to avoid TPU interference at end interfaces.
- Updated MAKI sleeve depth to symmetric end-clearance layout (`nominal length + 2*clearance`) for balanced two-cap fit.
- Added tripod-region reinforcement:
  - Mevo: enabled external bottom armor pad around tripod opening.
  - MAKI: added local side armor boss around tripod opening.
- Added/expanded fit reporting fields for cap insertion budget and axial/radial assembly margins.
- Regenerated active models and reports with the updated stack and validated cap/sleeve/TPU fit budgets.

### Report Folder Organization
- Added `reports/` subfolders to both case output roots:
  - `models/mevo_case/reports/`
  - `models/maki_case/reports/`
- Moved current JSON reports out of top-level case folders into those `reports/` subfolders.
- Updated all active generators so future report outputs are written to `reports/` by default.
- Added backward-compatible cleanup behavior so legacy top-level report files are auto-archived when present.

### Mevo TPU Output Cleanup
- Removed legacy Mevo TPU cap artifacts from top-level `models/mevo_case/`:
  - `mevo_start_tpu_front_cap.step`
  - `mevo_start_tpu_rear_cap.step`
  - `mevo_start_tpu_caps_report.json`
- Archived those legacy artifacts under `models/mevo_case/archive/` with timestamped names.
- Clarified docs so active Mevo TPU output is the single-file sleeve workflow:
  - `mevo_start_tpu_sleeve.step`
  - `mevo_start_tpu_sleeve_report.json`

### Unified Wall-Stack Update (Both Cameras)
- Updated baseline defaults to:
  - ASA wall thickness: `2.5 mm`
  - TPU wall thickness: `2.0 mm`
  - TPU internal clearance to camera: `0.2 mm`
  - TPU-to-ASA radial gap target: `0.1 mm`
- Applied defaults in both Mevo and MAKI generators so reports now reflect this stack.

### TPU Sleeve Workflow Update
- Mevo TPU output switched from `mevo_start_tpu_liner.*` to `mevo_start_tpu_sleeve.*`.
- MAKI TPU output switched from `maki_live_tpu_liner.*`/unibody preference to `maki_live_tpu_sleeve.*`.
- Added thin front/rear edge-wrap geometry for TPU sleeves (perimeter hold only, not full-face TPU caps).
- Legacy TPU outputs are archived automatically and no longer shown at case-folder top level.

### Model Output Organization
- Reorganized model outputs into:
  - `models/mevo_case/`
  - `models/maki_case/`
- Moved existing Mevo and MAKI STEP/JSON outputs into their respective subfolders.
- Updated script default output paths to keep future generations organized:
  - Mevo scripts now default to `models/mevo_case/`
  - MAKI scripts now default to `models/maki_case/`
- Updated README documentation paths to match the new folder layout.
- Added automatic output archival in all generators:
  - existing files are moved into each case folder's `archive/` subfolder with timestamped filenames before new files are written.

### Mevo TPU Nesting Compatibility
- Added `scripts/generate_mevo_start_tpu_liner.py` to generate a TPU inner sleeve that is dimensioned to fit inside the existing Mevo ASA shell.
- Added auto-fit thickness budgeting:
  - reads `models/mevo_start_case_report.json`,
  - computes maximum TPU wall thickness allowed by current ASA clearance and requested assembly gap,
  - clamps to fit-safe thickness.
- Added Mevo TPU output artifacts:
  - `models/mevo_start_tpu_liner.step`
  - `models/mevo_start_tpu_liner_report.json`
- Added fit-stack reporting fields for radial/axial remaining margins and alignment of tripod/vent openings relative to ASA shell coordinates.
- Updated docs (`README.md`, `README_MEVO_CASE.md`) with the new generator and usage.

### MAKI Sleeve Vent Update
- Updated MAKI ASA sleeve vent logic to enforce a tripod-side 3-panel vent pattern:
  - `8` vents on the primary panel,
  - plus `8` vents on each directly adjacent panel (`24` total).
- Switched enforced vent pattern cutting to deep box subtraction for full wall penetration.
- Preserved tripod opening alignment logic from STEP-derived feature mapping.

### MAKI Front Cap Bezel Inversion
- Updated MAKI front cap geometry to an inverted bezel profile:
  - center panel recessed,
  - outer rim proud/raised,
  - insertion plug moved to the rear side.
- Rear cap geometry kept unchanged.
- Added tuning parameters to `generate_maki_live_caps.py`:
  - `--front-recess-depth`
  - `--front-recess-inset`

### MAKI TPU One-Piece Unibody
- Added `scripts/generate_maki_live_tpu_unibody.py` to create a single connected TPU unit (liner + front + rear fused).
- New outputs:
  - `models/maki_case/maki_live_tpu_unibody.step`
  - `models/maki_case/maki_live_tpu_unibody_report.json`
- Default behavior archives legacy separate TPU parts into `models/maki_case/archive/` so top-level shows only the current unibody TPU output.

### Mevo Rear Closure De-duplication
- Updated `scripts/generate_mevo_case.py` so `mevo_start_case_back_plate.step` is no longer exported by default.
- Added optional flag `--include-back-plate` for legacy scenarios only.
- Default Mevo output path now avoids duplicate rear closure artifacts when front/rear cap workflow is used.

### Project Baseline and Repository Packaging
- Organized the workspace for Git version control with:
  - root `README.md` (project-wide overview),
  - `CHANGELOG.md` (this file),
  - `.gitignore` tuned for CAD workflow artifacts.
- Standardized workflow around smooth B-REP generation (`build123d` / OpenCascade) and STEP exports.

### Mevo Start
- Implemented/maintained parametric Mevo two-piece case generation:
  - sleeve/body model,
  - rear closure plate,
  - report output JSON.
- Enforced symmetric capsule-style front profile logic for clean extension from corrected lens-cap reference.
- Added dedicated cap generator with profile presets:
  - ASA caps,
  - TPU caps.
- Added rear tripod-relief notch support on rear Mevo cap.
- Set rear Mevo I/O cutouts as optional/default-off pending exact measured alignment confirmation.
- Generated current Mevo outputs:
  - `mevo_start_case_body.step`
  - `mevo_start_case_back_plate.step`
  - `mevo_start_case_report.json`
  - `mevo_start_front_cap.step`
  - `mevo_start_rear_cap.step`
  - `mevo_start_caps_report.json`
  - `mevo_start_tpu_front_cap.step`
  - `mevo_start_tpu_rear_cap.step`
  - `mevo_start_tpu_caps_report.json`

### BirdDog MAKI Live
- Implemented/maintained parametric ASA sleeve generator from MAKI reference STEP/PDF dimensions.
- Increased sleeve insertion clearance per request (+2 mm over previous fit pass).
- Reworked side geometry to avoid faceted rectangle-chain approximations and preserve smooth curved panels.
- Added/mirrored extracted side features:
  - tripod mount opening alignment,
  - vent slot extraction and application across multi-panel side faces.
- Implemented TPU liner generator:
  - snug inner fit for camera body,
  - bumper zones,
  - mirrored vent/tripod openings aligned with ASA sleeve.
- Implemented MAKI cap generator (ASA + TPU profiles) with end-face cutout extraction.
- Generated current MAKI outputs:
  - `maki_live_case_sleeve.step`
  - `maki_live_case_report.json`
  - `maki_live_tpu_liner.step`
  - `maki_live_tpu_liner_report.json`
  - `maki_live_front_cap.step`
  - `maki_live_rear_cap.step`
  - `maki_live_caps_report.json`
  - `maki_live_tpu_front_cap.step`
  - `maki_live_tpu_rear_cap.step`
  - `maki_live_tpu_caps_report.json`

### Validation Summary
- Current primary outputs export as STEP and have been validated as B-REP solids.
- Mevo rear cap transient secondary-solid artifact was removed by exporting only largest resulting solid.
- Vents/cutouts for MAKI are extraction-driven from the source STEP, with report files recording detected/applied counts.

### Current Status
- Core deliverables are in place for both camera platforms:
  - hard ASA outer-shell workflow,
  - TPU companion parts,
  - cap generation pipelines.
- Remaining precision work is primarily iterative cutout alignment/tuning to exact hardware fit checks after first physical print.

### Next Planned Adjustments
- Mevo:
  - capture exact rear port/button map from measured hardware and enable tuned rear cap I/O cutouts.
- MAKI:
  - verify front/rear cap cutout exactness against real device plug-in tests,
  - tighten any cutout offsets with measured print fit feedback.

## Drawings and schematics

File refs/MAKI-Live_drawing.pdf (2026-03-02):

1

A

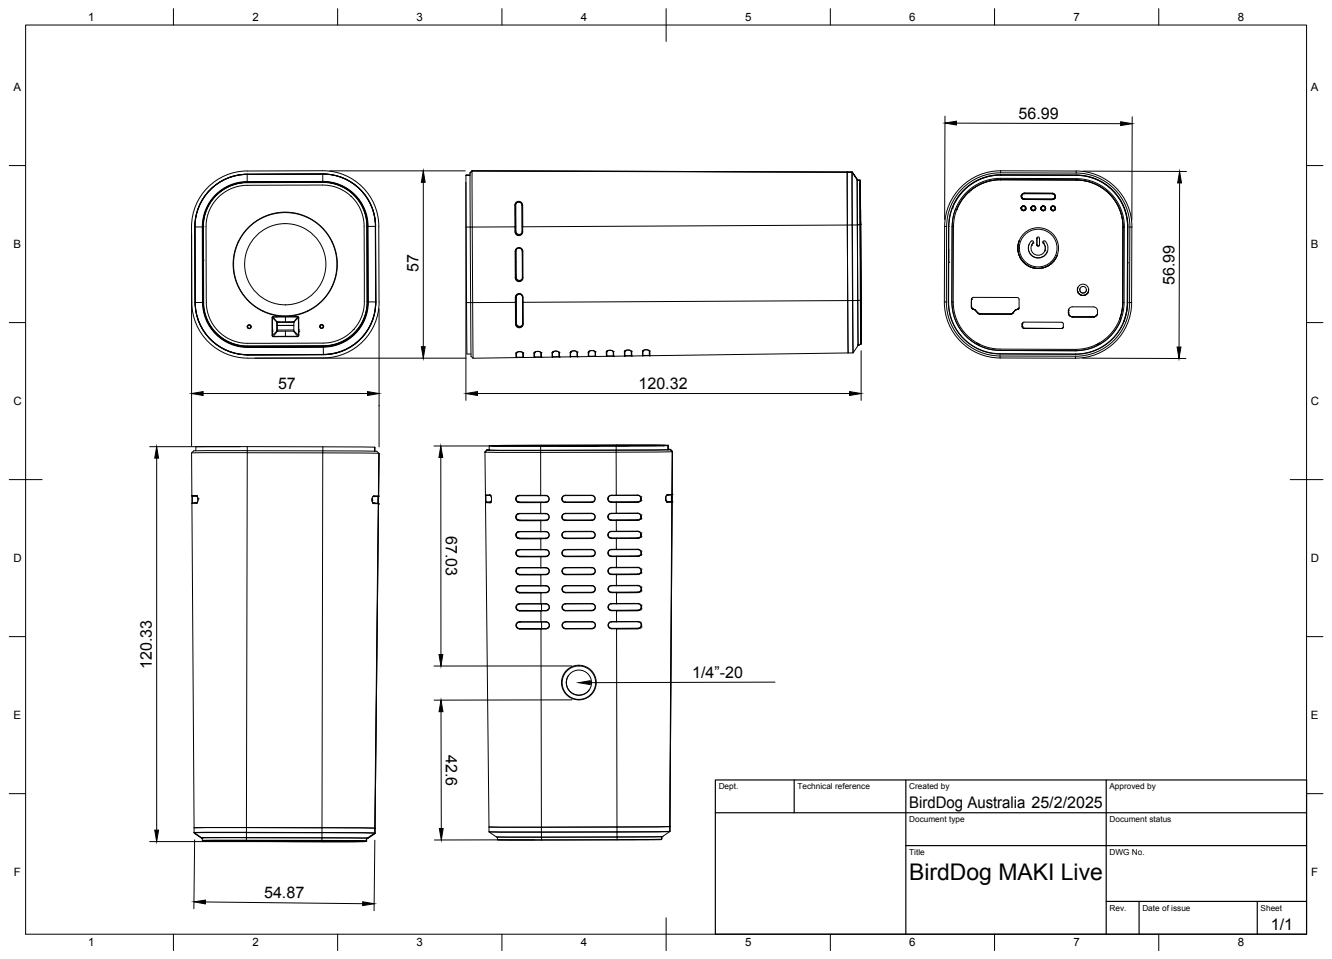
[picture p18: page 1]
Dept.; Technical reference; Created by; Approved by; Document type; Document status; Title; DWG No.; Rev.; Date of issue; Sheet; BirdDog Australia

BirdDog MAKI Live

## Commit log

2026-03-02 Initial project import: Mevo + MAKI parametric case pipeline
    [Mevo_Start_lens_cover_corrected.stl, cold-case-v2.f3d, maki_live_case_sleeve.step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]
2026-03-02 Add Mevo TPU liner auto-fit generator for ASA shell nesting
    [mevo_start_tpu_liner.step]
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2026-03-02 Add automatic model archiving and seed case archives
    [maki_live_case_sleeve_20260302_093640.step, maki_live_front_cap.step, maki_live_front_cap_20260302_093741.step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]
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2026-03-02 Invert MAKI front cap bezel profile with rear-side plug
    [maki_live_front_cap.step, maki_live_front_cap_20260302_094433.step, maki_live_rear_cap.step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]
2026-03-02 Add one-piece MAKI TPU unibody workflow and archive separate TPU parts
    [maki_live_tpu_front_cap_20260302_094918.step, maki_live_tpu_liner_20260302_094918.step, maki_live_tpu_rear_cap_20260302_094918.step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]
2026-03-02 Make Mevo back plate export opt-in to avoid duplicate rear cap
    [mevo_start_case_back_plate_20260302_095225.step, mevo_start_case_body_20260302_095225.step]
2026-03-02 Apply 2.5/2.0 wall stack and switch TPU outputs to edge-wrap sleeves
    [maki_live_case_sleeve_20260302_095913.step, maki_live_front_cap_20260302_095942.step, maki_live_rear_cap_20260302_095942.step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]
2026-03-02 Clean Mevo TPU outputs to single active sleeve artifact
    [mevo_start_tpu_front_cap_20260302_101126.step, mevo_start_tpu_rear_cap_20260302_101126.step]
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2026-03-02 Harden Mevo/MAKI assembly fit stack and move ASA walls to 3mm
    [maki_live_case_sleeve.step, maki_live_case_sleeve_20260302_103435.step, maki_live_front_cap_20260302_103504.step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]
2026-03-02 Fix Mevo tripod hole and enforce through-cut aligned MAKI vents
    [maki_live_case_sleeve.step, maki_live_case_sleeve_20260302_121132.step, maki_live_case_sleeve_20260302_121425.step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]
2026-03-02 Add Mevo dual-material body workflow with separate ASA back cap
    [mevo_start_back_cap_asa.step, mevo_start_back_cap_asa_20260302_125942.step, mevo_start_body_dual_material.step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]
2026-03-02 Set Mevo bottom tripod hole to 1 inch across ASA and TPU bodies
    [mevo_start_back_cap_asa_20260302_130713.step, mevo_start_body_dual_material.step, mevo_start_body_dual_material_20260302_130713.step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]
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2026-03-02 Fix Mevo dual-body ovular profile and open front default
    [mevo_start_back_cap_asa.step, mevo_start_back_cap_asa_20260302_142556.step, mevo_start_body_dual_material.step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]
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2026-03-02 Fix Mevo dual-material fit to 34x75.5x87 envelope
    [mevo_start_back_cap_asa_20260302_144513.step, mevo_start_body_dual_material_20260302_144513.step]
2026-03-02 Fix MAKI cap cutout extraction and Mevo cutout alignment defaults
    [maki_live_case_sleeve_20260302_151514.step, maki_live_rear_cap_20260302_151445.step, maki_live_rear_cap_20260302_151609.step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]
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2026-03-02 Fix MAKI tripod through-cuts and regenerate validated case outputs
    [maki_live_case_sleeve_20260302_154657.step, maki_live_case_sleeve_20260302_155219.step, maki_live_case_sleeve_20260302_155656.step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]
2026-03-02 Fix MAKI vent layout to 24+6 and correct slot orientation
    [maki_live_case_sleeve.step, maki_live_case_sleeve_20260302_161120.step, maki_live_tpu_sleeve.step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]
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2026-03-02 Correct MAKI vent panel orientation and flip side trio end
    [maki_live_case_sleeve.step, maki_live_case_sleeve_20260302_162615.step, maki_live_tpu_sleeve.step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]
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2026-03-02 Match MAKI side trio vents to main style and trim front aperture
    [maki_live_body_dual_material_20260302_165624.step, maki_live_case_sleeve_20260302_165549.step, maki_live_rear_cap_20260302_165749.step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]
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2026-03-02 Fix MAKI side vent slot geometry/alignment and add front hood + rear cap contact
    [maki_live_body_dual_material.step, maki_live_body_dual_material_20260302_171949.step, maki_live_case_sleeve.step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]
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2026-03-02 Refine MAKI dual body vent geometry, tripod overlap, duck-bill hood, and rear-cap TPU coverage
    [maki_live_body_dual_material.step, maki_live_body_dual_material_20260302_175202.step, maki_live_case_sleeve.step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]
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2026-03-02 Adjust Mevo upper rear cutout, raise lens opening, and add front duck-bill visor
    [mevo_start_back_cap_asa_20260302_175755.step, mevo_start_back_cap_dual_material_20260302_175755.step, mevo_start_body_dual_material.step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]
2026-03-03 Fix MAKI tripod/vent side orientation and curve duck-bill root profile
    [maki_live_body_dual_material_20260302_180602.step, maki_live_case_sleeve.step, maki_live_case_sleeve_20260302_180530.step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]
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2026-03-05 Add snap-latch flexure clips to both MAKI and Mevo cases
    - 2 cantilever clips on body inner X walls (5x3x1mm beams, 0.6mm catch nubs)
    - Matching ridges on cap plugs for snap engagement
    - Mevo: clips in ASA body + ridge on TPU gasket plug
    - MAKI: clips in ASA sleeve + ridge on ASA rear cap plug
    - CLI: --no-snap-clips (body), --no-snap-ridge (MAKI cap)
    - All MAKI fit validation passing (0 collisions, all features OK)
2026-03-05 Add Mevo cap-to-body collision check in generator
    Checks ASA cap plate vs ASA shell at seated position after each generation.
    Reports intersection volume in JSON; warns if > 0.5 mm3.
    Current result: 0.0 mm3 (clean fit).
2026-03-05 Update CLAUDE.md with cold shoe, oval vents, snap clips, and collision check docs
    Documents all new features for both MAKI and Mevo cases: ISO 518 cold shoe
    mounts, oval top vent slots, snap-latch flexure clips, cap collision checking,
    and corrected MAKI rail overhang dimension.
2026-03-05 Add all current model outputs, archives, and updated scripts
    Includes latest STEP/JSON outputs for both MAKI and Mevo cases,
    archive versions, validation scripts, and all modified generator scripts
    with cold shoe, oval vents, snap clips, and collision check features.
    [maki_live_body_aligned.step, maki_live_body_aligned_20260303_004623.step, maki_live_body_aligned_20260303_004924.step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]
2026-03-05 Move Mevo cold shoe mount from bottom to top of capsule
    Plane.XZ normal is -Y in build123d, so offset(max_y) placed geometry
    at the bottom. Fixed by negating all XZ offsets and flipping extrusion
    directions so the cold shoe sits on the top (Y+) surface.
    [mevo_start_back_cap_dual_material.step, mevo_start_body_dual_material.step]
2026-03-05 Fix Mevo cold shoe: fill vent cutouts and conform to inner capsule curve
    Moved cold shoe geometry to after vent cuts so the fill pad re-fills
    any overlapping top vent slots. Extended fill pad depth to fully merge
    with the shell wall, then subtract the inner cavity capsule profile so
    the interior surface follows the smooth capsule curvature with no
    protruding ledges.
    [mevo_start_back_cap_dual_material.step, mevo_start_body_dual_material.step]
2026-03-05 Remove top vent slots under Mevo cold shoe pad from ASA and TPU
    Filter out top vent slots whose center falls within the cold shoe pad
    footprint. Removes the two rear-most vents (Z=59.15, Z=72.3) that were
    being cut through both layers underneath the cold shoe mount.
    [mevo_start_back_cap_dual_material.step, mevo_start_body_dual_material.step]
2026-03-05 Fix retention mechanism and update Mevo tripod cutout
    - MAKI: Fix cap friction ridge (was invisible due to Z misplacement,
    gasket subtraction erasure, and boolean fuse failures). Now uses
    Compound bundling after gasket subtraction with correct Z offset.
    - MAKI: Disable fragile snap clips on body, snap ridges on cap.
    - MAKI: Increase friction ridge size (0.8mm height, 1.5mm width body /
    1.0mm width cap) for effective press-fit retention.
    - Mevo: Remove Y-axis friction ridge strips on cap (extended past
    capsule dome into open space).
    - Mevo: Update bottom rectangular cutout to 2" x 1.25" (50.8 x 31.75mm).
    [maki_live_body_aligned.step, maki_live_body_dual_material.step, maki_live_rear_cap_aligned.step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]
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2026-03-06 Mevo: extend case length by 3/8 inch (87.80 to 97.325mm)
    Adds 9.525mm to TPU inner depth for better rear clearance.
    Downstream dims (vents, tripod, cap) auto-cascade.
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2026-03-06 Mevo: regenerate models with all 8 geometry adjustments
    Verified report:
    - body_depth: 100.325mm
    - LED from_bottom: 17.875mm
    - tripod center: 50.7875mm from front
    - cold shoe pad center: 85.325mm (flush with rear)
    - 4 detent pockets + 4 bumps with relief
    - 7 side vents per side
    - collision_pass: true
    [mevo_start_back_cap_dual_material.step, mevo_start_back_cap_dual_material_20260304_202326.step, mevo_start_back_cap_dual_material_20260304_203543.step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]
2026-03-06 Mevo: replace detent bumps with cantilever snap-latches + fix hood corner rounding
    Cantilever latch system: body pockets now include catch-shelf notches at front
    Z-edge; cap bumps become cantilever flex-tabs with U-channel relief (freed on
    3 sides) and triangular catches with stepped ramp for smooth insertion.
    Hood fix: build hood as separate BuildPart with 3D edge fillet (3/2/1mm
    fallback) instead of failing 2D fillet on curve-curve intersection vertices.
2026-03-08 MAKI: split to 3 separate STEP files + top-visor hood
    Split dual-material body into separate ASA shell and TPU frame outputs.
    Removed legacy combined assembly/alignment files. Hood changed from
    full circular tube to top-visor (clipped to body width).
    [maki_live_asa_shell.step, maki_live_body_aligned.step, maki_live_body_aligned_20260304_213231.step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]
2026-03-08 Mevo Start: split to 3 separate STEP files (ASA shell, TPU frame, back cap)
    Refactored generator to output individual material bodies instead of combined
    dual-material assemblies. Archives legacy combined files. Updated report format.
    [mevo_start_asa_shell.step, mevo_start_asa_shell_20260307_012312.step, mevo_start_asa_shell_20260307_012359.step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]
2026-03-08 Mevo Core: new parametric case generator with all iterative refinements
    Square 90x90mm cross-section with rounded corners (24mm ASA outer, 20mm TPU inner).
    Features: full circular tube lens hood (63.5mm depth), dual cold shoe mounts
    (top Y+ and left X-), thermal vents on all 4 sides with cold shoe filtering,
    2.5" tripod cutout shifted 1/4" toward rear, skeleton TPU frame with loft
    subtraction for smooth internal transitions, 0.25mm interface gap, 3mm extra
    insertion length. Back cap with port + power button cutouts.
    [mevo_core_asa_shell.step, mevo_core_asa_shell_20260307_011736.step, mevo_core_asa_shell_20260307_011756.step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]
2026-03-08 Zowietek 4K POV: new parametric case generator
    Rounded-rectangle profile (68.6x60.2x51mm device). Features: skeleton TPU frame,
    top-visor lens hood, dual tripod mounts (top + bottom), cold shoe on top rear,
    thermal vents with cold shoe filtering, ASA bumper ring back cap (open center
    for rear port/button access), 4-point cantilever latch retention.
    [zowietek_pov_asa_shell.step, zowietek_pov_asa_shell_20260307_012335.step, zowietek_pov_asa_shell_20260307_012356.step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]
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2026-03-09 Mevo Core: reduce extra length from 3mm to 1.5mm to eliminate axial jiggle
    Axial play reduced from 3.3mm to 1.8mm. Camera still fits with room for
    insertion but back cap now seats snugly against camera.
    [mevo_core_asa_shell.step, mevo_core_asa_shell_20260308_201712.step, mevo_core_back_cap_20260308_201712.step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]
2026-03-10 Mevo Core: add 8-point cantilever snap-fit clips + matching cap ridges
    Primary retention upgraded from bump-pockets-only to cantilever snap clips
    (2 per wall, 8 total) with 1mm catch nubs engaging matching 1mm ridges on
    the back cap plug. Existing 4-point bump pockets retained as secondary
    alignment. All fit checks pass, no collisions.
    [mevo_core_asa_shell.step, mevo_core_asa_shell_20260309_213521.step, mevo_core_back_cap_20260309_213521.step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]
2026-03-10 Mevo Core: reinforce lens hood base with tapered flare
    Hood connection to shell face was a thin annular wall (2.5mm). Added a cone
    frustum base: 6mm extra radius at root tapering to normal wall thickness over
    8mm depth. Significantly larger bonded footprint prevents breakage at the
    attachment point.
    [mevo_core_asa_shell_20260310_112522.step, mevo_core_back_cap_20260310_112522.step, mevo_core_tpu_frame_20260310_112522.step]
2026-03-11 Mevo Core: remove bump pockets, widen hood bore, add vent slots
    - Disable bump pockets (create ejection force against snap clips)
    - Hood inner bore +2.5mm clearance vs front face hole — ledge at attachment
    point gives more material at the stress concentration zone
    - Side vents 5→7 on no-cold-shoe side (+1 front, +1 back)
    - Left side (cold-shoe) gets 5 after filter (+1 front vs old 4)
    - Top vents 5→5 after filter with shifted positions (+1 closer to front)
    [mevo_core_asa_shell.step, mevo_core_asa_shell_20260310_222553.step, mevo_core_asa_shell_20260310_222727.step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]
2026-03-11 Mevo Core: replace snap clips with bayonet twist-lock back cap
    4 L-shaped channels cut into inner shell walls (entry slot + horizontal
    channel per wall). 4 matching tabs on cap plug. Insert straight with tabs
    aligned to entry slots, rotate CW (viewed from rear) to lock — tabs ride
    into channels and are positively retained axially. Rotate CCW to remove.
    14mm travel, 1.5mm radial depth, 0.4mm clearance. No bump pockets or
    snap clips; positive mechanical lock only.
    [mevo_core_asa_shell.step, mevo_core_asa_shell_20260310_235718.step, mevo_core_back_cap_20260310_235718.step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]
2026-03-11 Mevo Core: fix twist-lock walls, thin wall, +30% vents
    - Twist-lock channels reduced to X+ and Y- walls only (cold-shoe walls
    X- and Y+ removed to prevent conflicts and thin-wall issues)
    - tab_h 1.5->0.8mm: leaves 1.0mm of ASA wall backing instead of 0.7mm
    - tab_w 9->12mm, tab_t 2.5->3.0mm, travel 14->16mm for better engagement
    - Cap has 2 matching tabs (X+ and Y-) only
    - Side vents 20->26mm (+30%), top vents 24->31mm (+30%)
    [mevo_core_asa_shell.step, mevo_core_asa_shell_20260311_003700.step, mevo_core_back_cap_20260311_003700.step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]
2026-03-11 Both cases: replace twist-lock/bumps with external cantilever latches + rear TPU bumpers
    Mevo Core:
    - Remove bayonet twist-lock (physically impossible on square plug)
    - Add 4 external cantilever latch arms on outer shell walls with hook nubs
    - Add rear corner bumpers to TPU skeleton frame (protects all 8 corners)
    Zowietek:
    - Disable top tripod cutout (was creating large hole overlapping cold shoe)
    - Make all vents 40% longer (sides 18→25.2mm, top 22→30.8mm)
    - Add flared Cone base to lens hood for reinforcement
    - Replace friction ridge bumps with 4 external cantilever latches
    - Add rear corner bumpers to TPU skeleton frame
    [mevo_core_PETG_SHELL.3mf, mevo_core_asa_shell.step, mevo_core_asa_shell_20260311_090958.step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]
2026-03-11 Fix external latch arms: overlap 1mm into shell wall for proper boolean fusion
    Latch arms were positioned flush with shell surface — no volume overlap
    caused _largest_solid() to discard them. Now arms start 1mm inside the
    rear face, ensuring solid fusion with the shell body.
    Also adjusts collision check threshold to account for expected latch-plate
    intersection volume.
    [mevo_core_asa_shell_20260311_091834.step, mevo_core_asa_shell_20260311_091918.step, mevo_core_back_cap_20260311_091834.step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]
2026-03-11 Fix TPU rear corner bumpers: extend through relief zone with overlap for fusion
    Rear bumpers were placed entirely inside the already-subtracted relief zone,
    creating floating solids discarded by _largest_solid(). Now bumpers:
    - Extend from 2mm inside surviving corner legs through full relief zone
    - Include L-shaped wall pieces matching corner leg geometry
    - Add small shelf pads on rear face at each corner for edge protection
    [mevo_core_asa_shell_20260311_092256.step, mevo_core_back_cap_20260311_092256.step, mevo_core_tpu_frame_20260311_092256.step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]
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2026-03-19 Fix Zowietek cap clearance with TPU liner
    [zowietek_pov_asa_shell_20260318_203956.step, zowietek_pov_back_cap_20260318_203956.step, zowietek_pov_tpu_frame.step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]
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2026-03-19 Fix Zowietek cold shoe dual rails
    [zowietek_pov_asa_shell.step, zowietek_pov_back_cap.step, zowietek_pov_tpu_frame.step]
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2026-03-19 Add Zowietek shell clearance for cap seating
    [zowietek_pov_asa_shell.step, zowietek_pov_asa_shell.stl, zowietek_pov_asa_shell.stp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]
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2026-03-21 Flip MAKI shade to top side
    [maki_live_asa_shell.step, maki_live_asa_shell_20260321_162846.step, maki_live_case_sleeve.step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]
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2026-03-22 Fix MAKI shade vent relief punching
    [maki_live_asa_shell.step, maki_live_asa_shell_20260321_223123.step, maki_live_tpu_frame_20260321_223123.step]
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2026-06-22 Restore Mevo Core latch notch clearance
    [mevo_core_asa_shell_20260621_233832.step, mevo_core_back_cap_20260621_233832.step]
2026-06-22 Shorten Mevo Core shade side skirts
    [mevo_core_asa_shell.step, mevo_core_asa_shell_20260621_234324.step, mevo_core_back_cap_20260621_234324.step]
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2026-06-22 Replace shade drip bars with angled skirts
    [maki_live_asa_shell.step, maki_live_asa_shell_20260622_115800.step, mevo_core_asa_shell.step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]
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2026-06-22 Fix Mevo Core hood root open edges
    [mevo_core_asa_shell.step, mevo_core_asa_shell_20260622_144431.step]
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2026-06-24 Increase Mevo Core rear opening clearance
    [mevo_core_asa_shell_20260624_081944.step, mevo_core_back_cap_20260624_081944.step]
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2026-06-24 Shorten AVKANS lens hood
    [avkans_go4k_added_lens_hood_only.stl, avkans_go4k_cults_shade_with_lens_hood.stl]
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2026-06-25 Replace AVKANS hood root lip profile
    [avkans_go4k_added_lens_hood_only.stl, avkans_go4k_cults_shade_with_lens_hood.stl]
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2026-06-29 Shorten Mevo Core lens hood
    [mevo_core_asa_shell_20260629_172135.step, mevo_core_back_cap_20260629_172135.step]
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
